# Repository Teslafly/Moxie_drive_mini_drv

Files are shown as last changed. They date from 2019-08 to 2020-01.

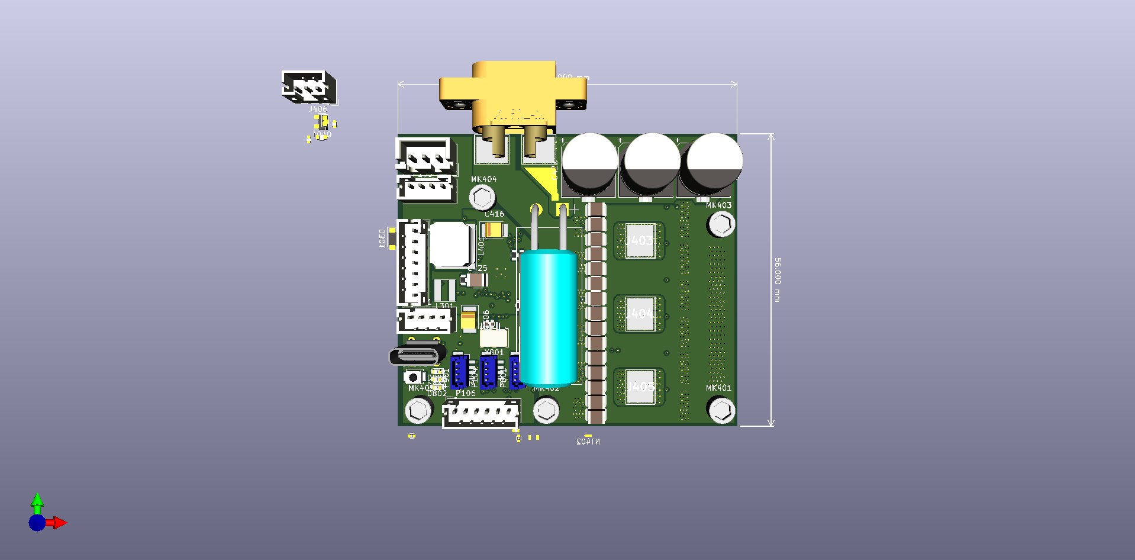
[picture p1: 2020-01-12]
MoxiE_drive mini front notrace 1-11-20.png

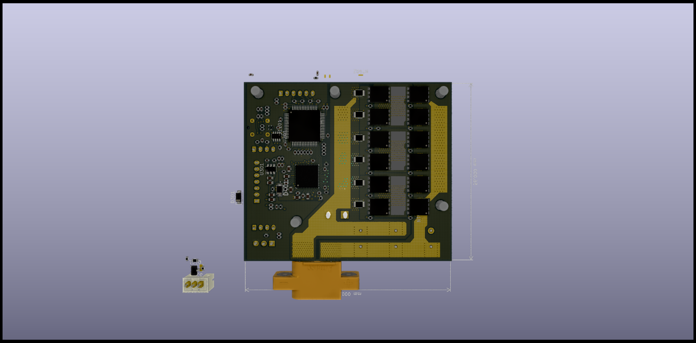
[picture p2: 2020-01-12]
MoxiE_drive mini back 1-11-20.png

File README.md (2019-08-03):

# Moxie_drive_mini_drv
A motor drive based off https://github.com/vedderb/bldc-hardware using the drv8353 and toshiba fets

MoxiE-Drive - high power 12-75v motor controller
=============

design

Forged from the remminants of the oppressed vesc 6.
Raised on a diet of endless sphere and equals zero posts.
destined for a fight to the death in hilariously brutal Power Wheels Racing Series.
I give to you, the MoxiE-Drive.

This the Hardware for my derivitive of the Vesc-project.

## Schematic top level


## Layout -made with KiCad!-


## 3D views



Have a look at this post for a tutorial on how to get started:
http://vedder.se/2015/01/vesc-open-source-esc/

Made with KiCad 5

wonderfulfailure.wordpress.com

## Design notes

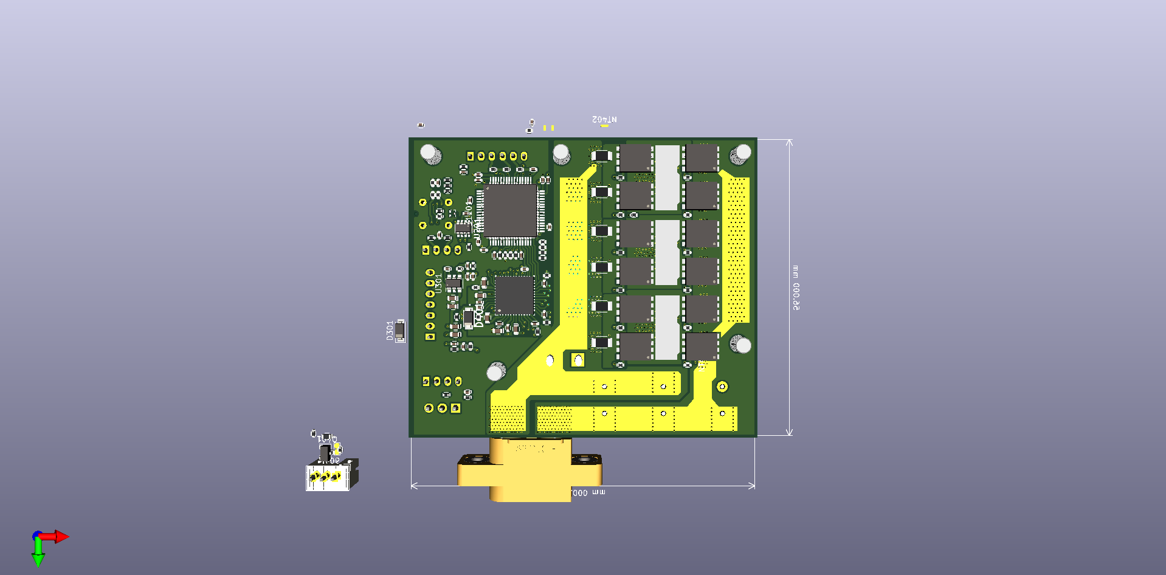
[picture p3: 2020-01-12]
MoxiE_drive mini back notrace 1-11-20.png

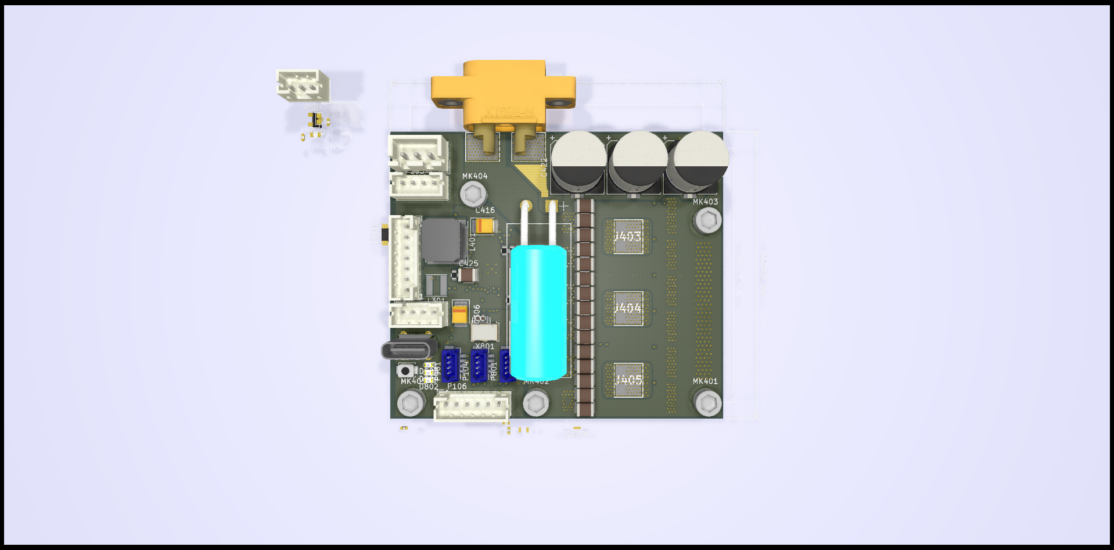
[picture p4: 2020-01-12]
MoxiE_drive mini front 1-11-20.png

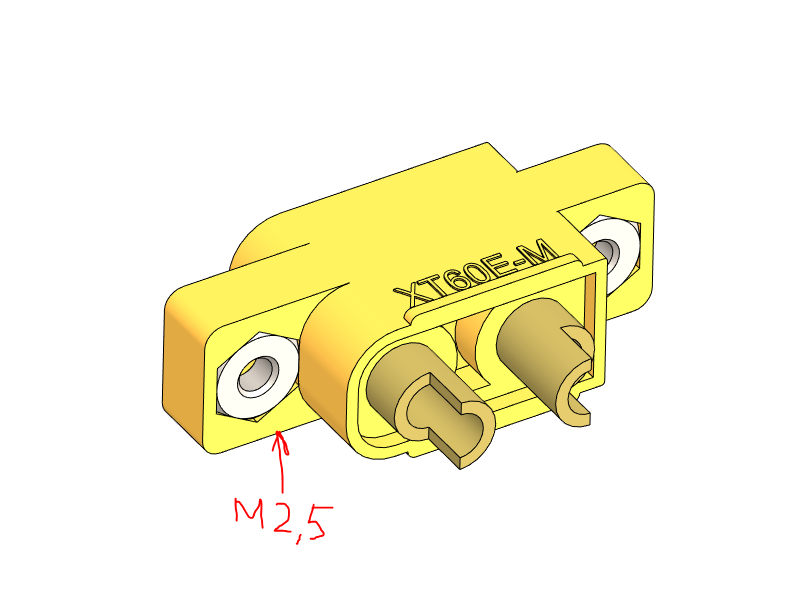
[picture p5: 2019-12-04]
3dmodels/xt-60-family-1.snapshot.6/v25.PNG

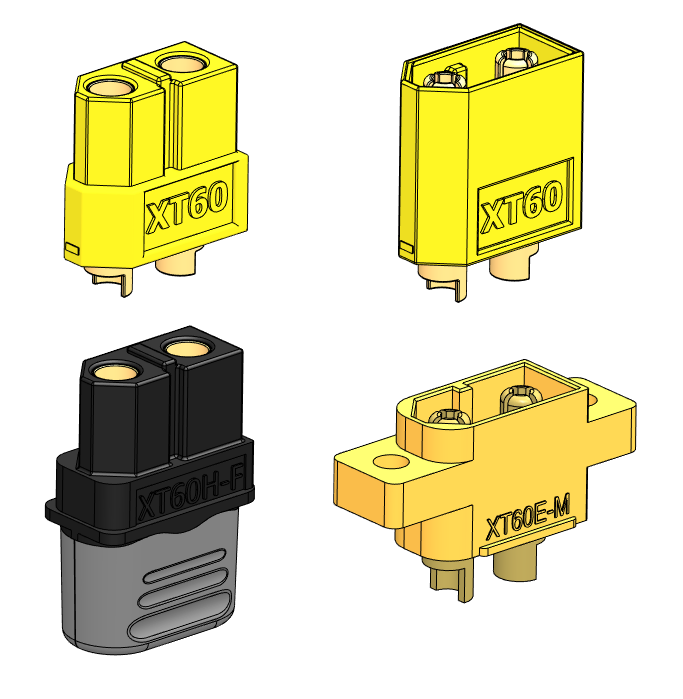
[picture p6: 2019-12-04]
3dmodels/xt-60-family-1.snapshot.6/xt60 fam.PNG

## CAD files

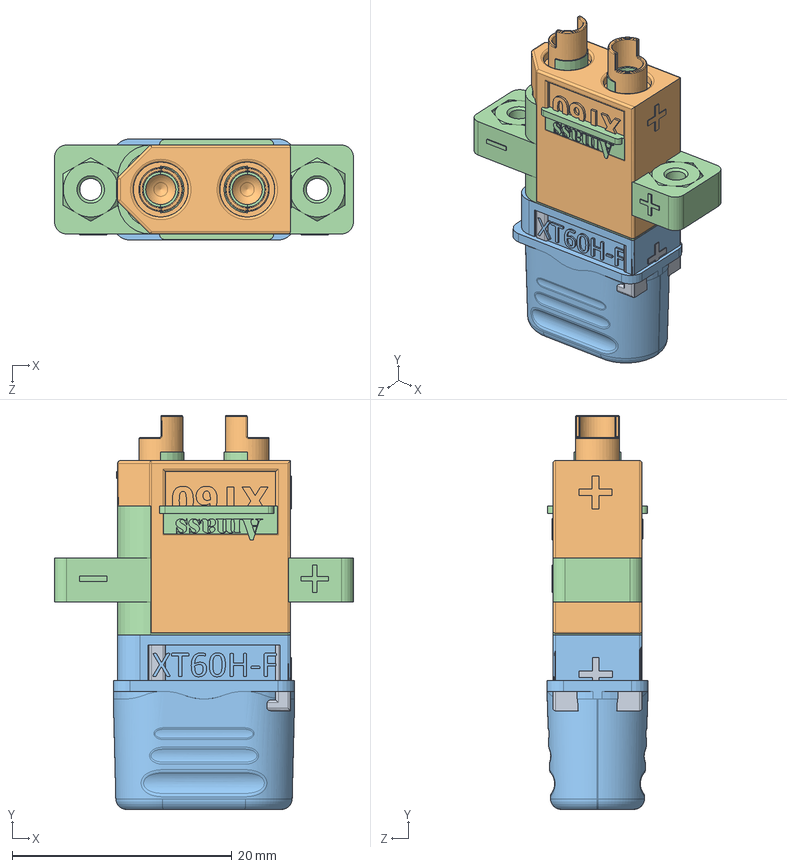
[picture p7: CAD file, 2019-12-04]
3dmodels/xt-60-family-1.snapshot.6/XT60 connect ASM.SLDASM
27.2 x 35.8 x 9.20 mm
XT60 Female Connector
XT60 Male Connector
XT60H-F
XT60E-M

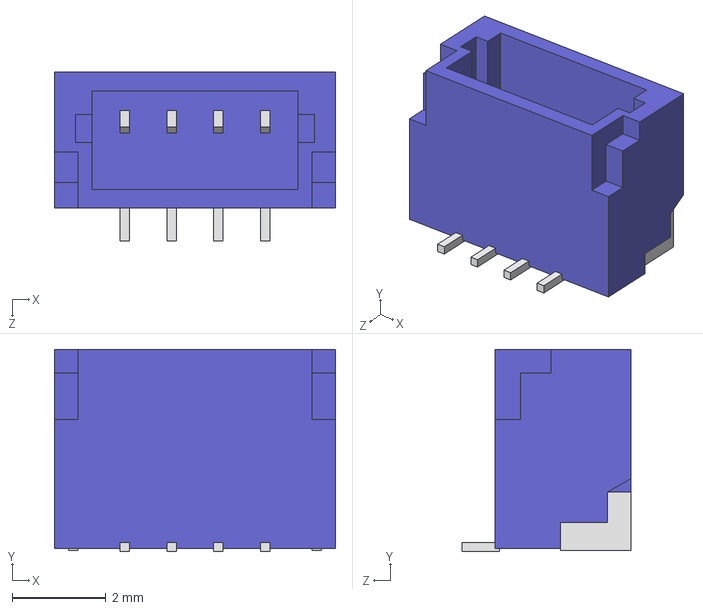
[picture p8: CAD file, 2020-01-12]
3dmodels/BM04B-SRSS-TB.STEP
6.00 x 4.32 x 3.60 mm

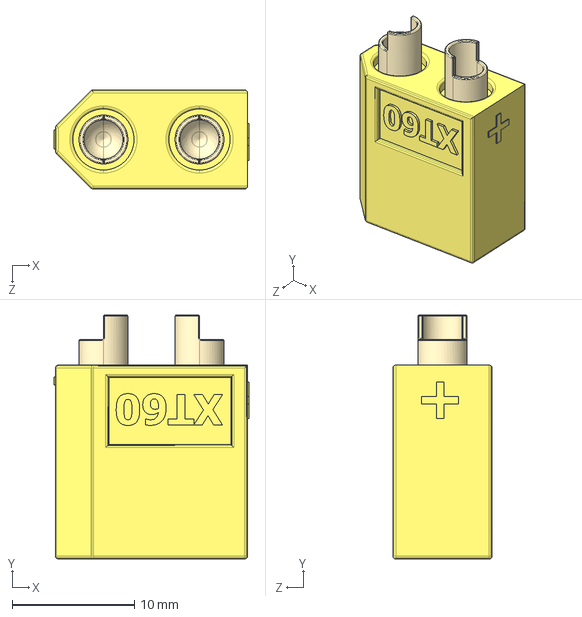
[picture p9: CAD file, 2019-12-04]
3dmodels/xt-60-family-1.snapshot.6/XT60 Male Connector.STEP
15.9 x 20.0 x 8.13 mm

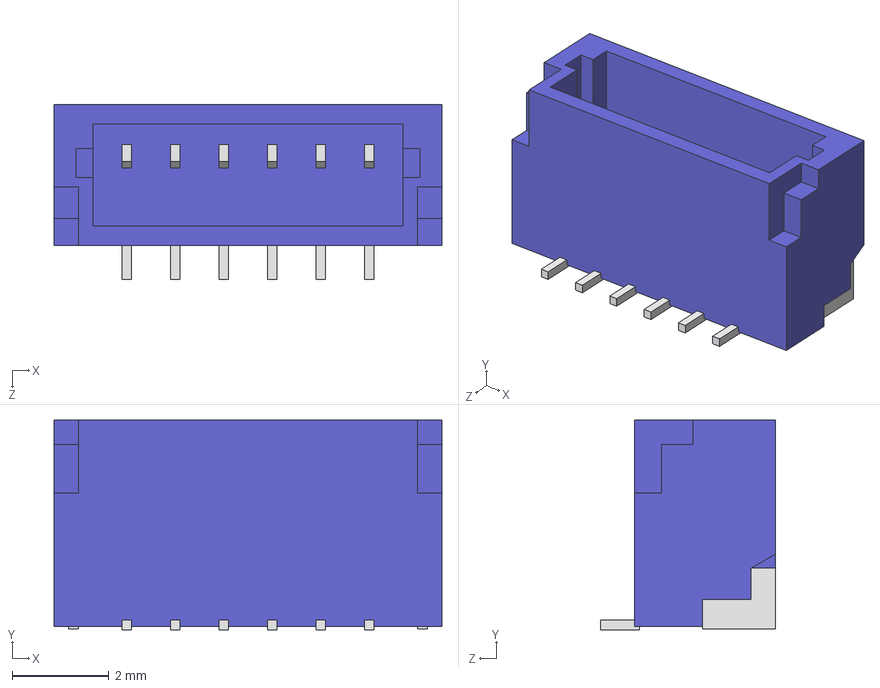
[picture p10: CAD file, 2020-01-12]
3dmodels/BM06B-SRSS-TB.STEP
8.00 x 4.32 x 3.60 mm

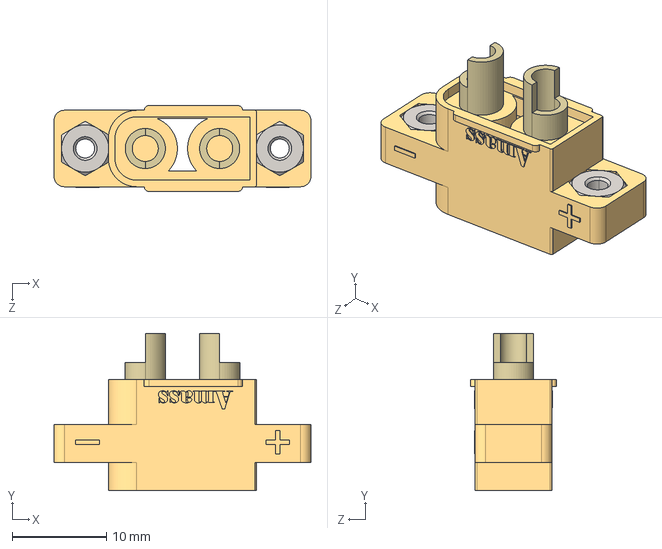
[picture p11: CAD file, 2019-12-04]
3dmodels/xt-60-family-1.snapshot.6/XT60E-M.STEP
27.2 x 16.7 x 9.10 mm

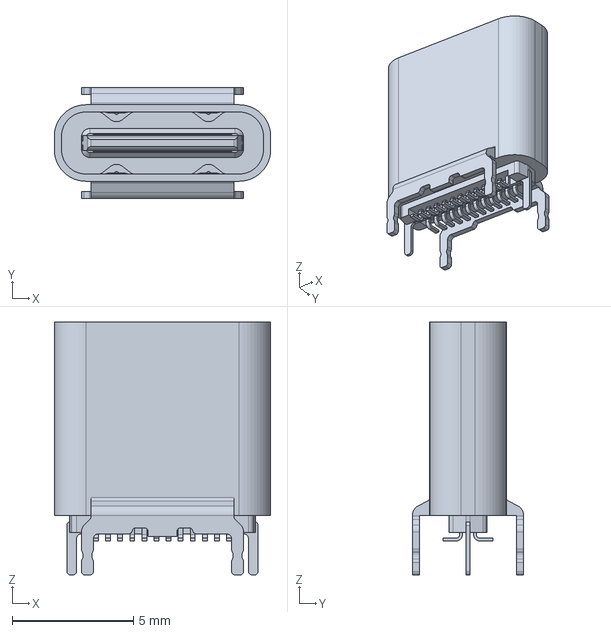
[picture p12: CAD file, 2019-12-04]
3dmodels/usb c 2047110001.stp
8.94 x 4.60 x 10.4 mm

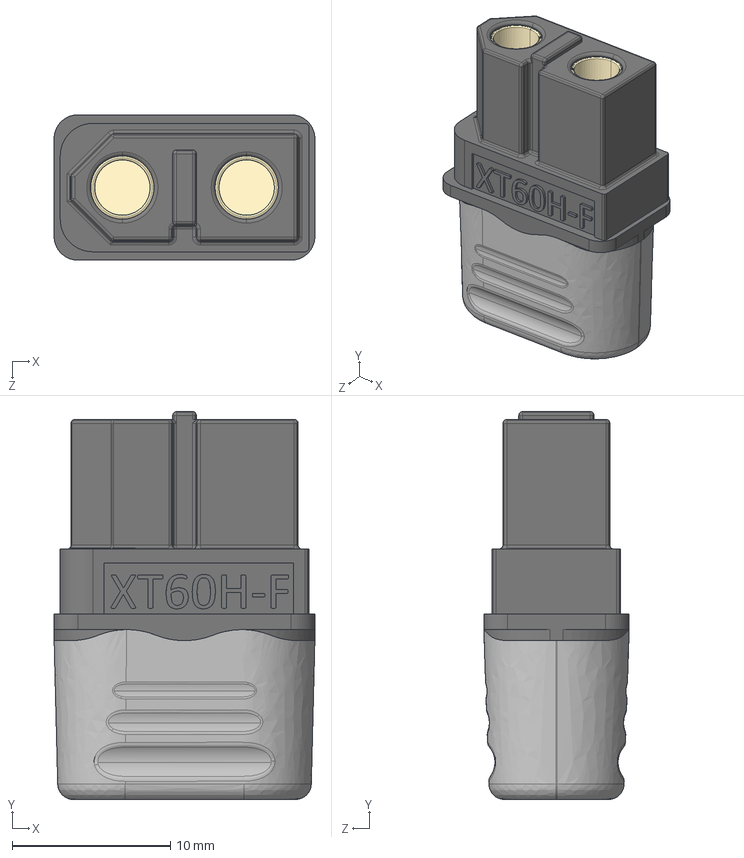
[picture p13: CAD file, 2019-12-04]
3dmodels/xt-60-family-1.snapshot.6/XT60H-F.STEP
16.5 x 24.5 x 9.20 mm

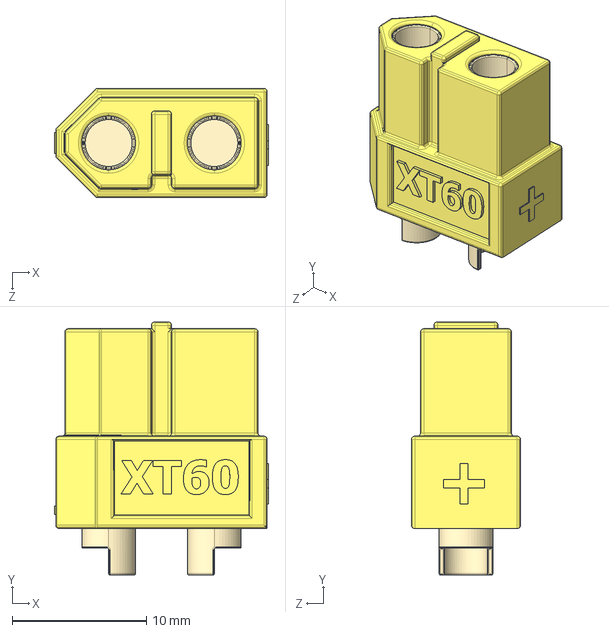
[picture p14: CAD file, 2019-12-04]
3dmodels/xt-60-family-1.snapshot.6/XT60 Female Connector.STEP
15.9 x 18.8 x 8.13 mm

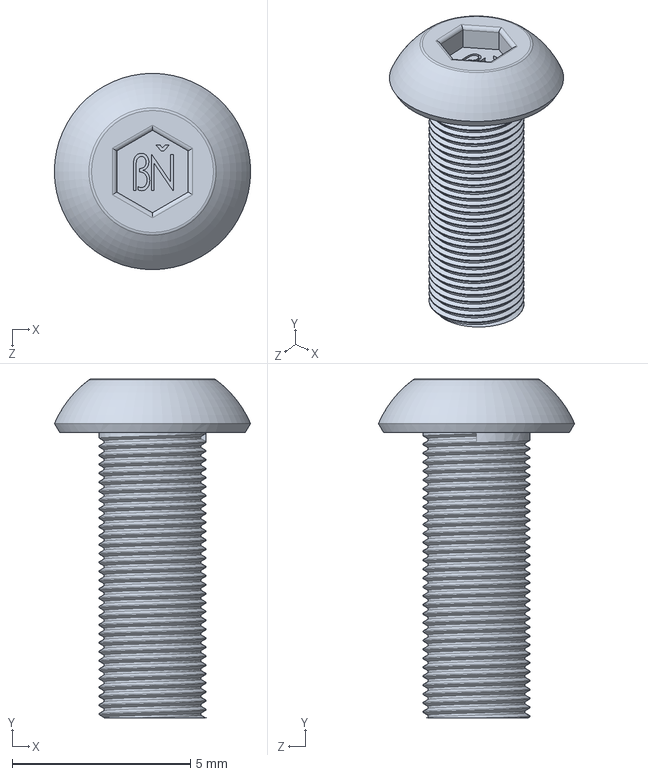
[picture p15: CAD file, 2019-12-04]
3dmodels/MachineScrews/Screw_Machine_M3x8.SLDPRT
5.50 x 9.50 x 5.50 mm

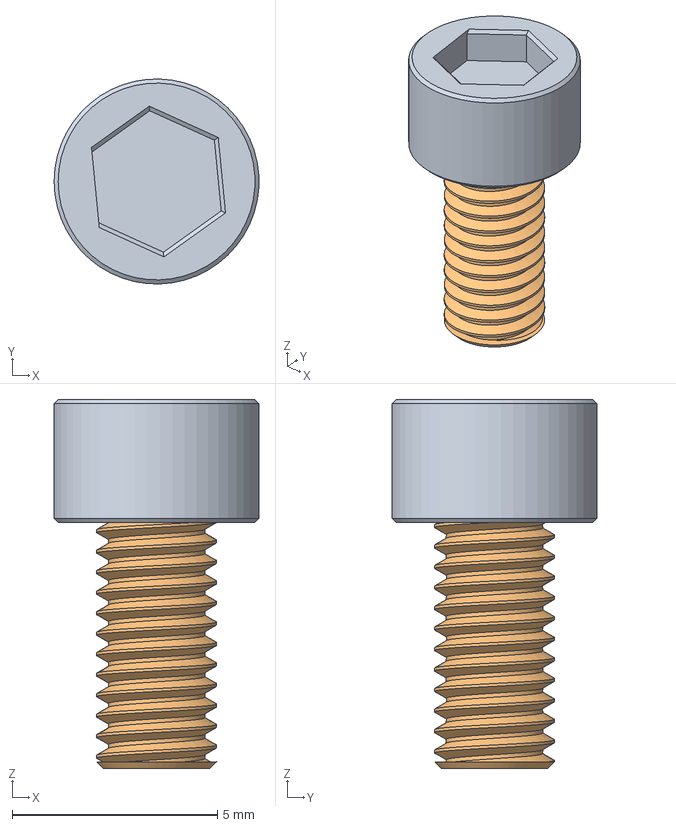
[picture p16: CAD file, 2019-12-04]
3dmodels/screw-m3-6mm-1.snapshot.1/screw M3 6mm .step
5.00 x 5.00 x 9.00 mm

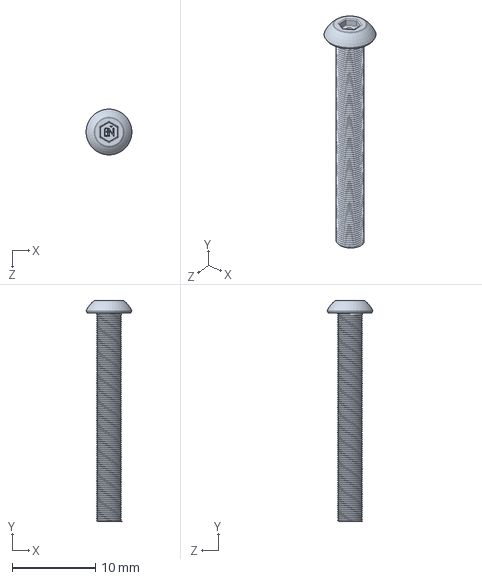
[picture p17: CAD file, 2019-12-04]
3dmodels/MachineScrews/Screw_Machine_M3x25.SLDPRT
5.50 x 26.5 x 5.50 mm

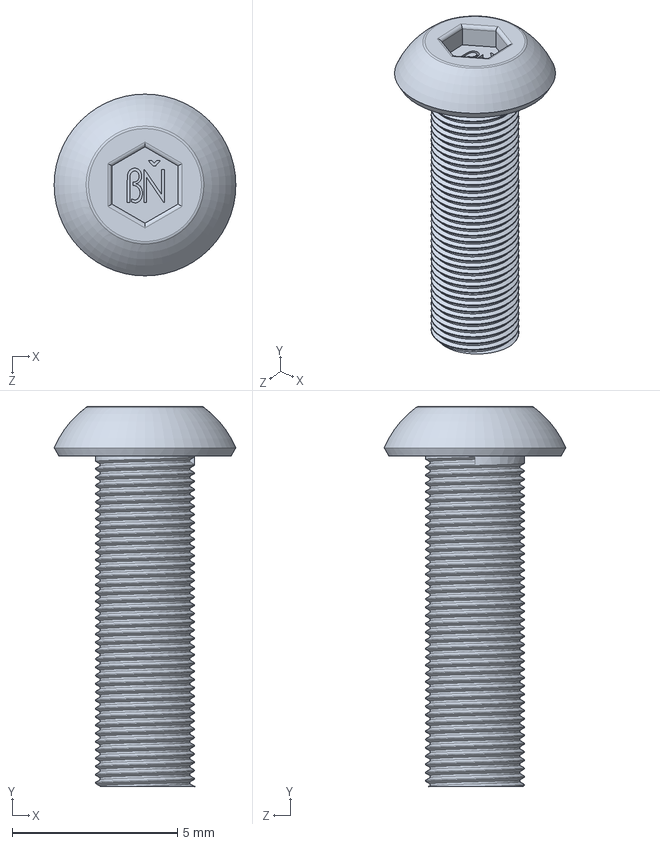
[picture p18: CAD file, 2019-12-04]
3dmodels/MachineScrews/Screw_Machine_M3x10.SLDPRT
5.50 x 11.5 x 5.50 mm

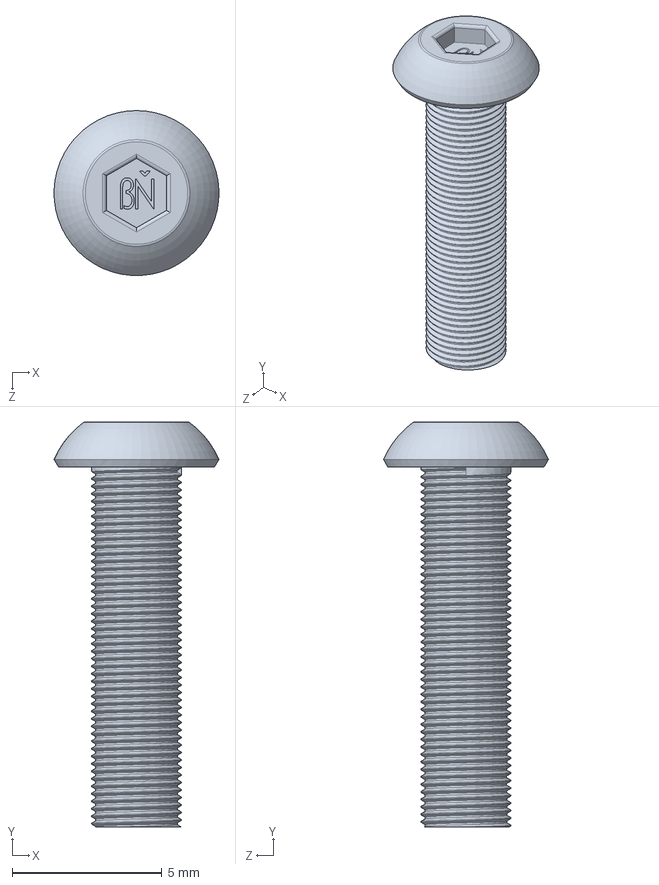
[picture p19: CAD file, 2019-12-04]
3dmodels/MachineScrews/Screw_Machine_M3x12.SLDPRT
5.50 x 13.5 x 5.50 mm

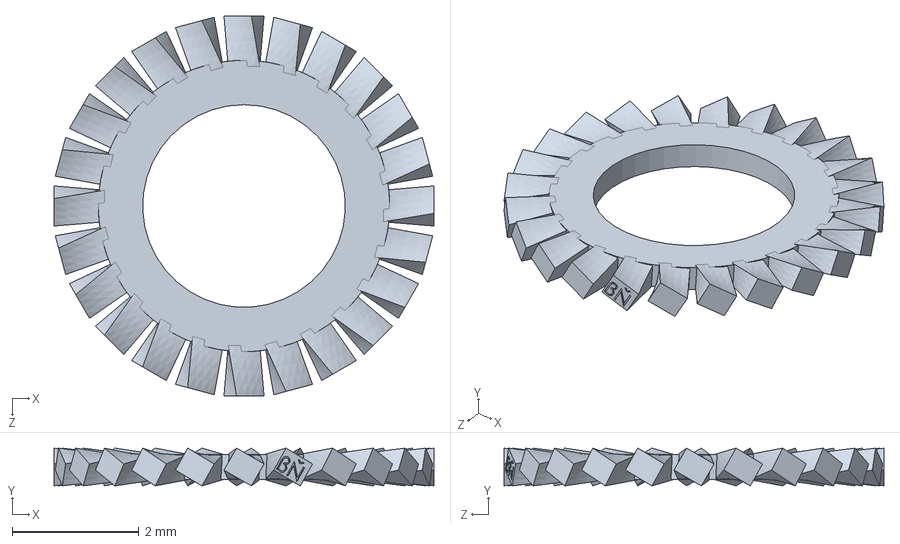
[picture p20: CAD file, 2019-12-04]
3dmodels/MachineScrews/Lock Washer_Bolt _M3.SLDPRT
6.00 x 0.596 x 6.00 mm

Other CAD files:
3dmodels/MachineScrews/Screw_Machine_M3x14.SLDPRT
3dmodels/MachineScrews/Nut_Machine_M3x2.SLDPRT
3dmodels/MachineScrews/Screw_Machine_M3x18.SLDPRT
3dmodels/MachineScrews/Screw_Machine_M3x16.SLDPRT
3dmodels/MachineScrews/Screw_Machine_M3x.SLDPRT
3dmodels/MachineScrews/Screw_Machine_M3x20.SLDPRT
3dmodels/MachineScrews/Screw_Machine_M3x6.SLDPRT
3dmodels/xt-60-family-1.snapshot.6/XT60 Female Connector.SLDPRT
3dmodels/xt-60-family-1.snapshot.6/XT60 Male Connector.SLDPRT
3dmodels/xt-60-family-1.snapshot.6/XT60E-M.SLDPRT
3dmodels/xt-60-family-1.snapshot.6/XT60H-F.SLDPRT

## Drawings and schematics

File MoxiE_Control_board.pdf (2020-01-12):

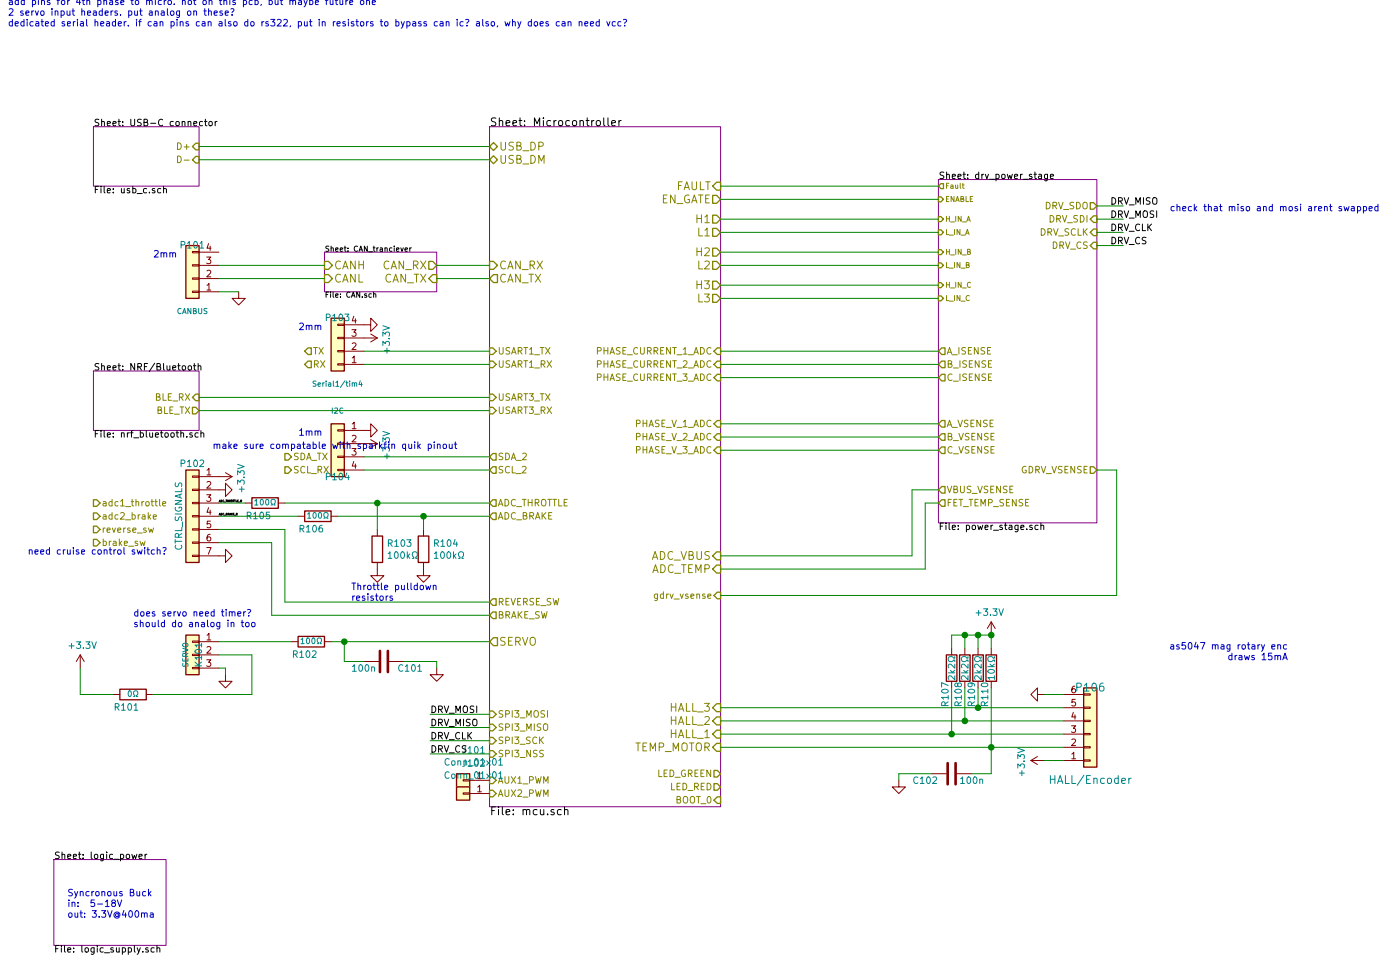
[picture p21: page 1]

add pins for 4th phase to micro. not on this pcb, but maybe future one
2 servo input headers. put analog on these?
dedicated serial header. if can pins can also do rs322, put in resistors to bypass can ic? also, why does can need vcc?

check that miso and mosi arent swapped

Sheet: NRF/Bluetooth File: nrf_bluetooth.sch BLE_TX

make sure compatable with sparkfin quik pinout

Throttle pulldown resistors need cruise control switch? Syncronous Buck

does servo need timer?
should do analog in too

as5047 mag rotary enc draws 15mA

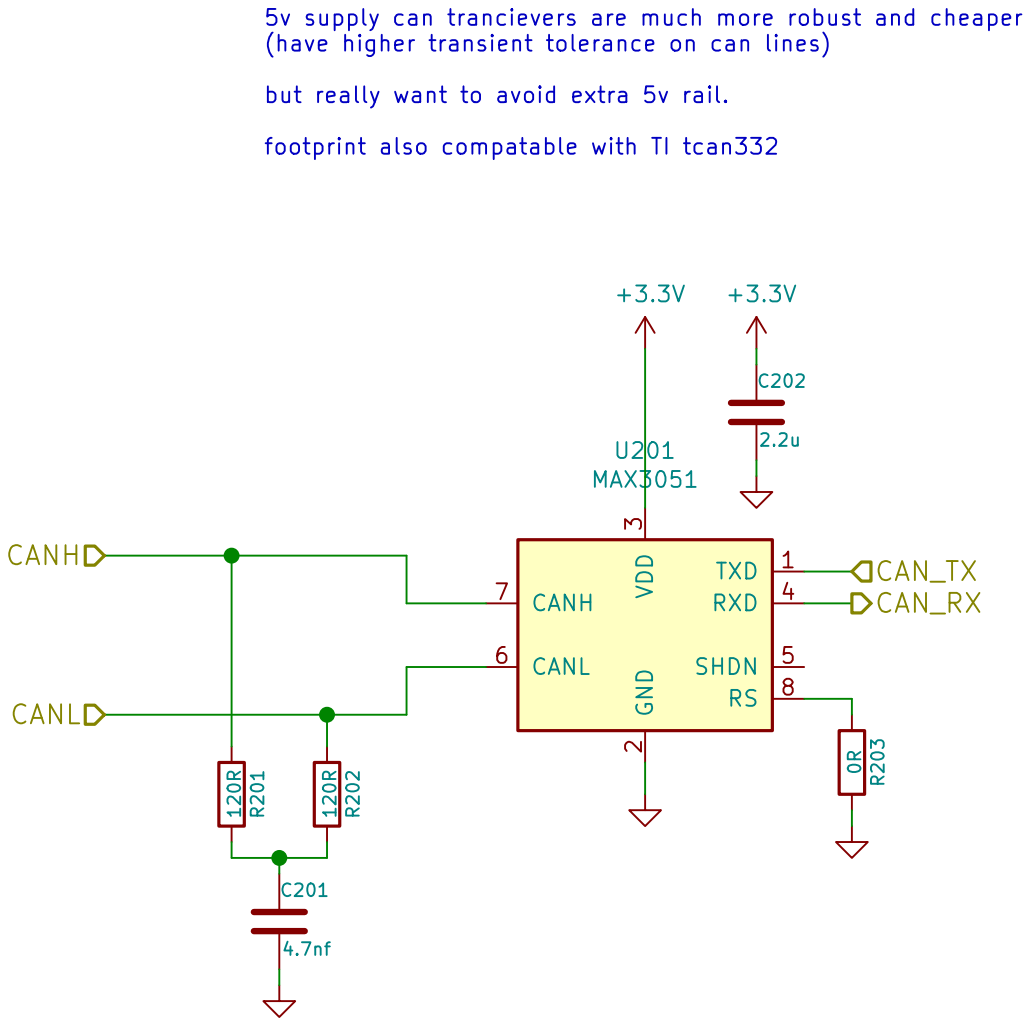
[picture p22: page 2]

5v supply can trancievers are much more robust and cheaper
(have higher transient tolerance on can lines)

but really want to avoid extra 5v rail.

footprint also compatable with TI tcan332

3 RXD 4 SHDN 5 CANL 6 CANH 7 RS 8 U201 MAX3051 R203 0R

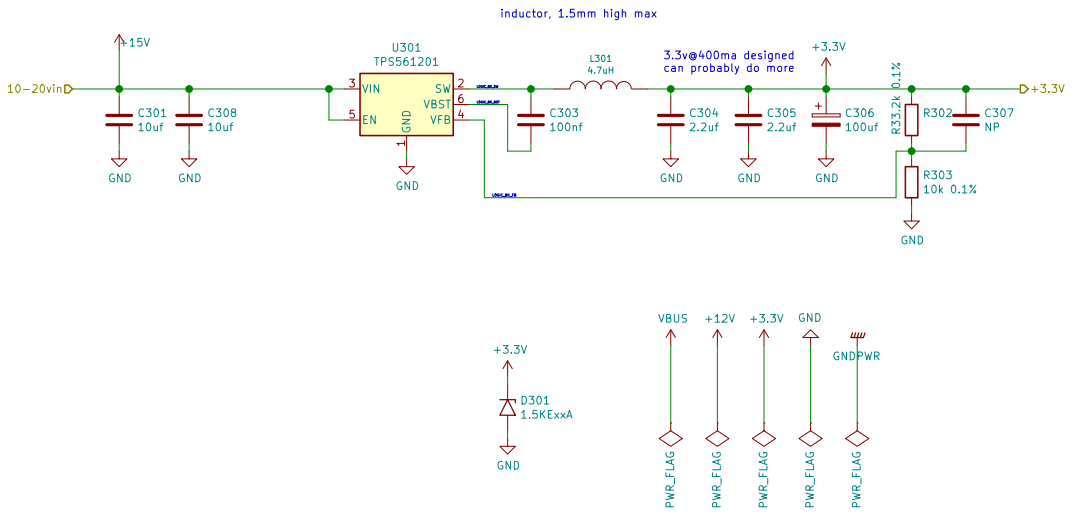
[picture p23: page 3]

1 SW 2 VIN 3 VFB 4 EN 5 VBST 6 U301 TPS561201 D301

3.3v@400ma designed
can probably do more

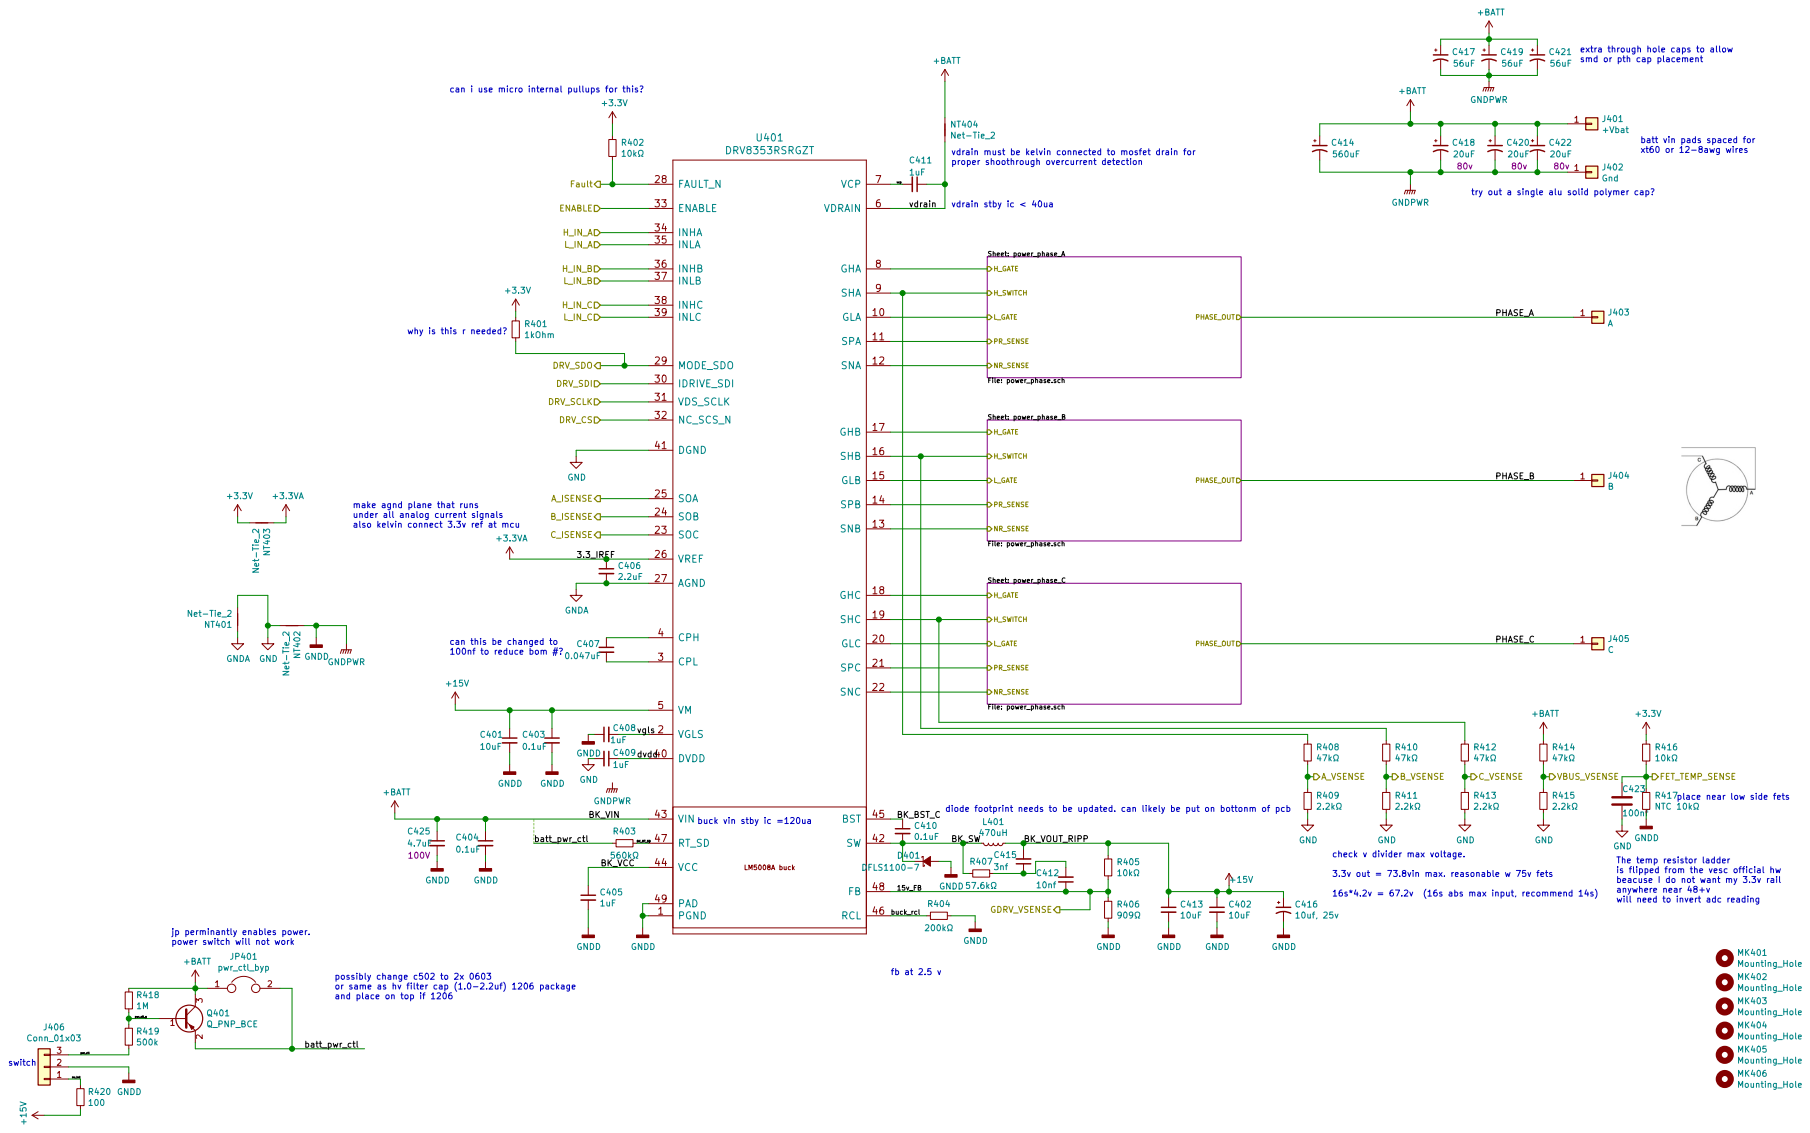
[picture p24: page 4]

extra through hole caps to allow
smd or pth cap placement

can i use micro internal pullups for this?

batt vin pads spaced for
xt60 or 12-8awg wires

vdrain must be kelvin connected to mosfet drain for proper shoothrough overcurrent detection

try out a single alu solid polymer cap?

under all analog current signals also kelvin connect 3.3v ref at mcu why is this r needed?

make agnd plane that runs

diode footprint needs to be updated. can likely be put on bottonm of pcb

buck vin stby ic =120ua

check v divider max voltage. 3.3v out = 73.8vin max. reasonable w 75v fets 16s*4.2v = 67.2v (16s abs max input, recommend 14s)

is flipped from the vesc official hw
beacuse I do not want my 3.3v rail
anywhere near 48+v
will need to invert adc reading

jp perminantly enables power.
power switch will not work

possibly change c502 to 2x 0603
or same as hv filter cap (1.0-2.2uf) 1206 package
and place on top if 1206

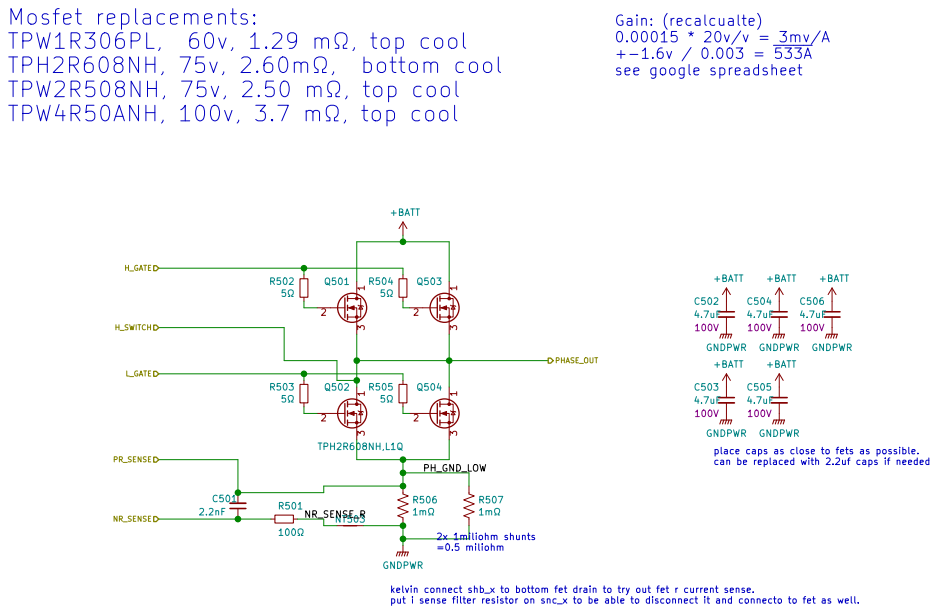
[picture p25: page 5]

GNDPWR
place caps as close to fets as possible.
can be replaced with 2.2uf caps if needed

kelvin connect shb_x to bottom fet drain to try out fet r current sense.
put i sense filter resistor on snc_x to be able to disconnect it and connecto to fet as well.

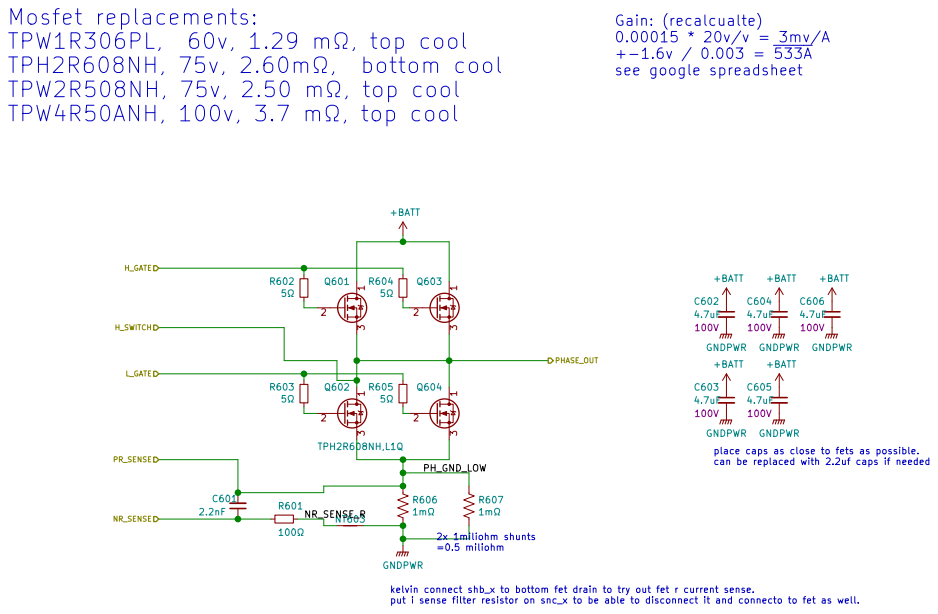
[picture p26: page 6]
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

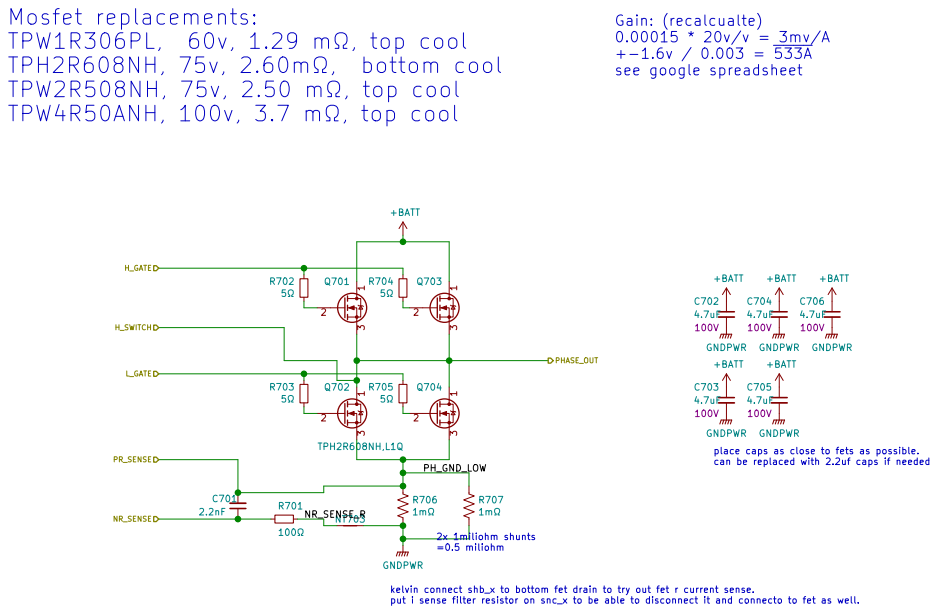
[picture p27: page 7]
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

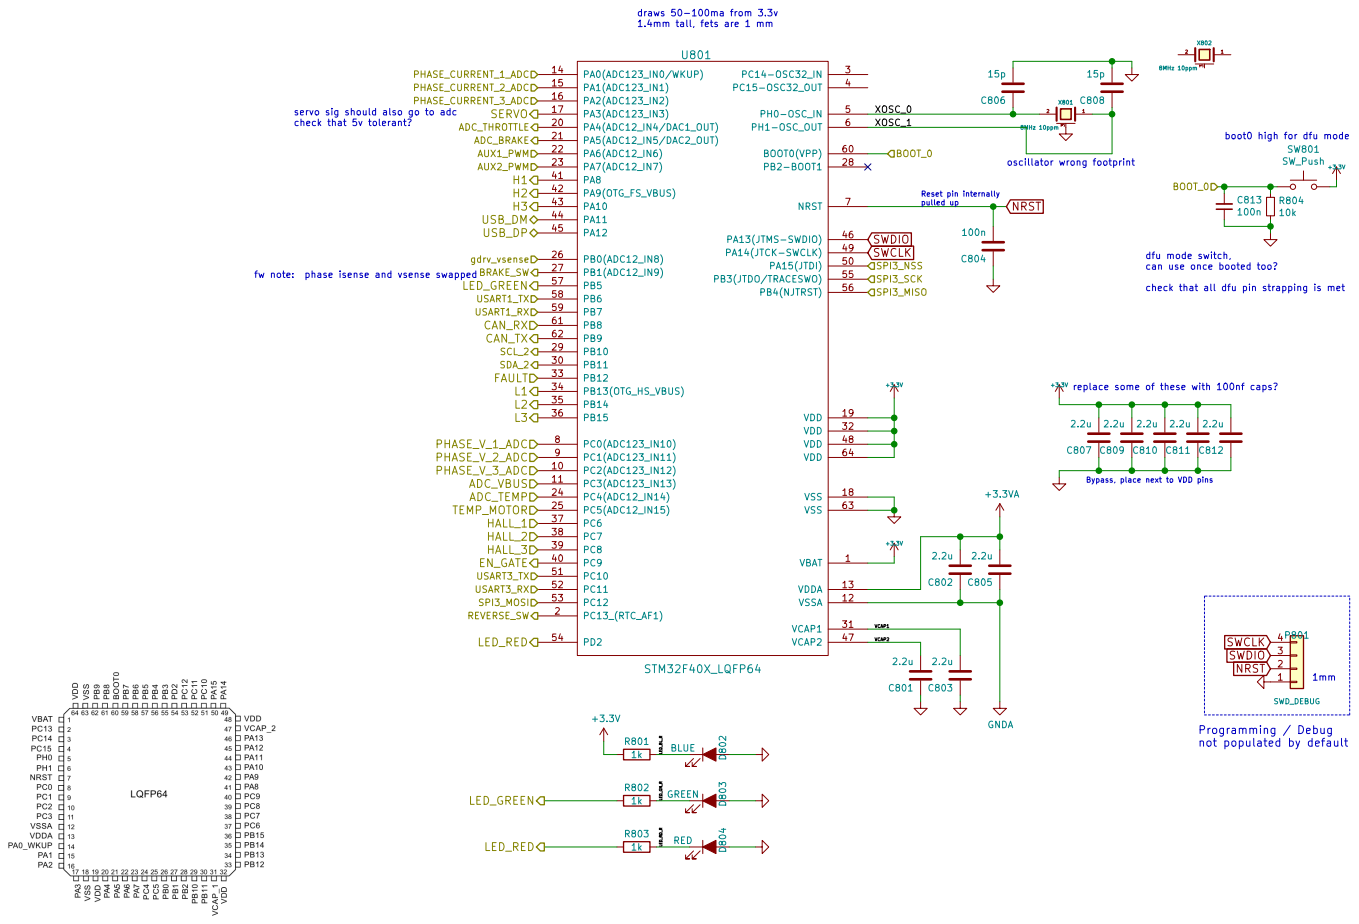
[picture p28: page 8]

draws 50-100ma from 3.3v 1.4mm tall, fets are 1 mm

servo sig should also go to adc
check that 5v tolerant?

fw note: phase isense and vsense swapped

check that all dfu pin strapping is met

replace some of these with 100nf caps?

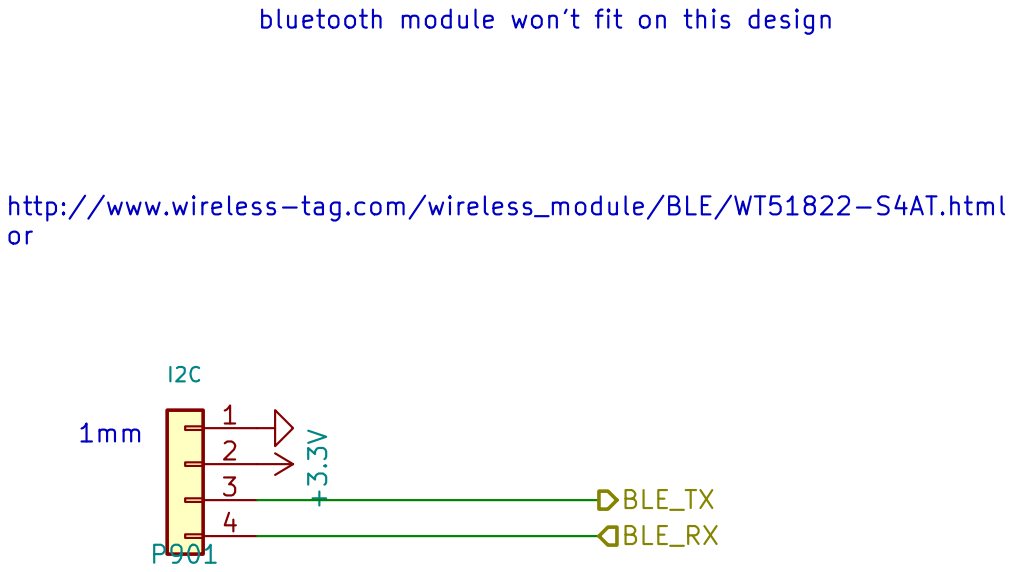
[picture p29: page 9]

bluetooth module won't fit on this design

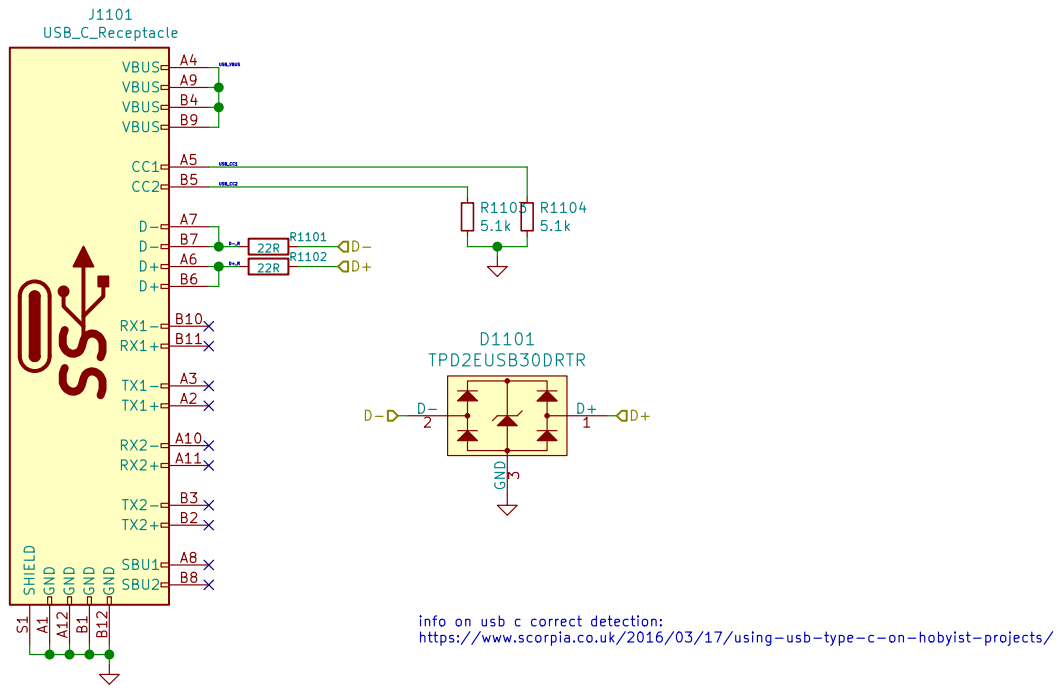
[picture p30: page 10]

info on usb c correct detection: https://www.scorpia.co.uk/2016/03/17/using-usb-type-c-on-hobyist-projects/

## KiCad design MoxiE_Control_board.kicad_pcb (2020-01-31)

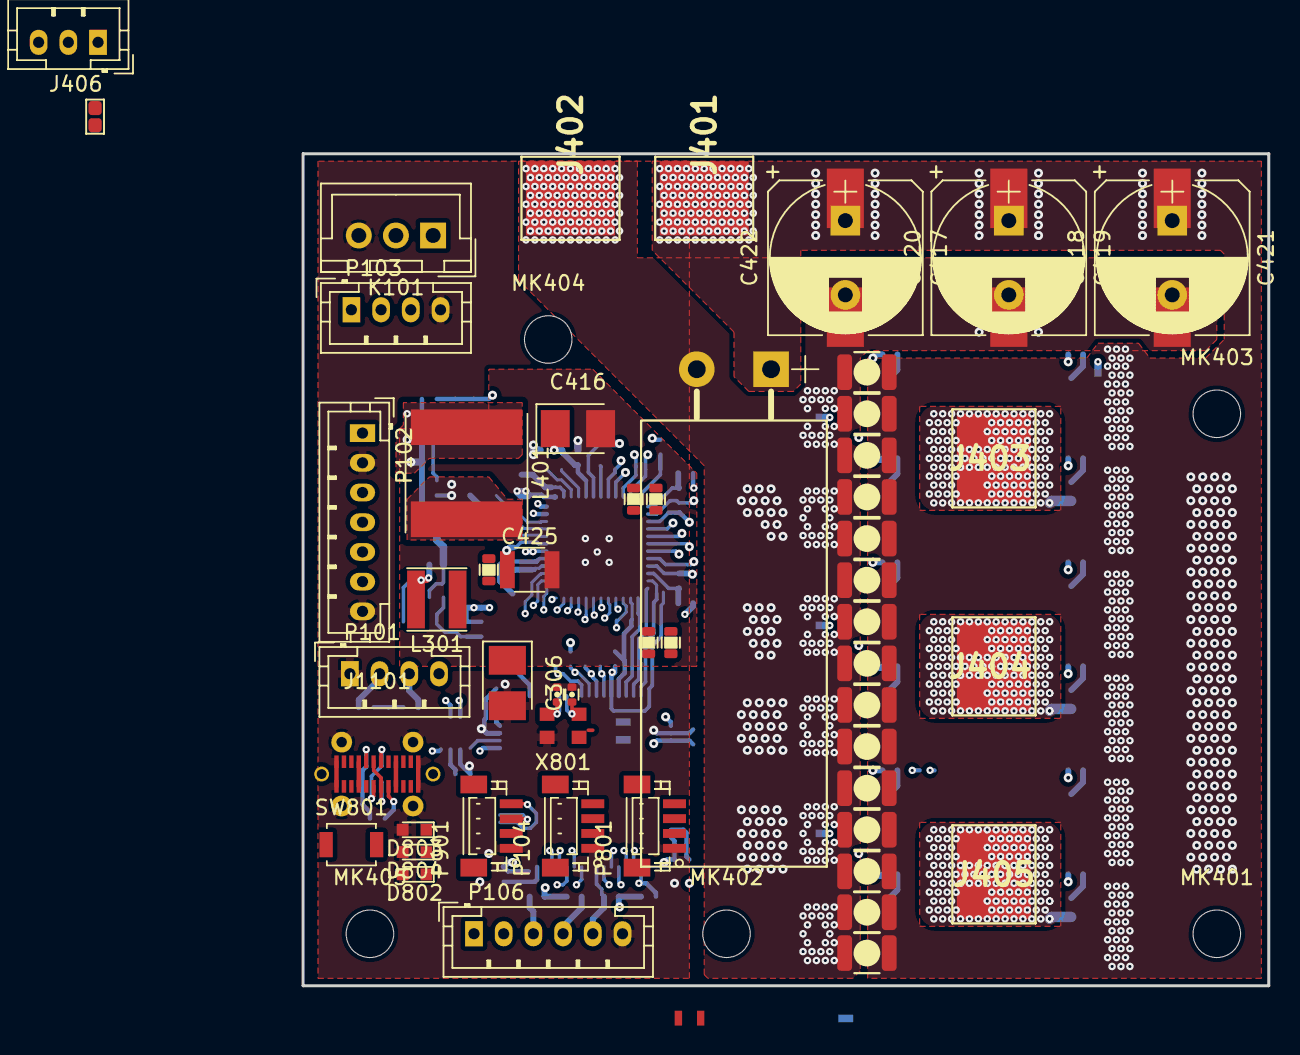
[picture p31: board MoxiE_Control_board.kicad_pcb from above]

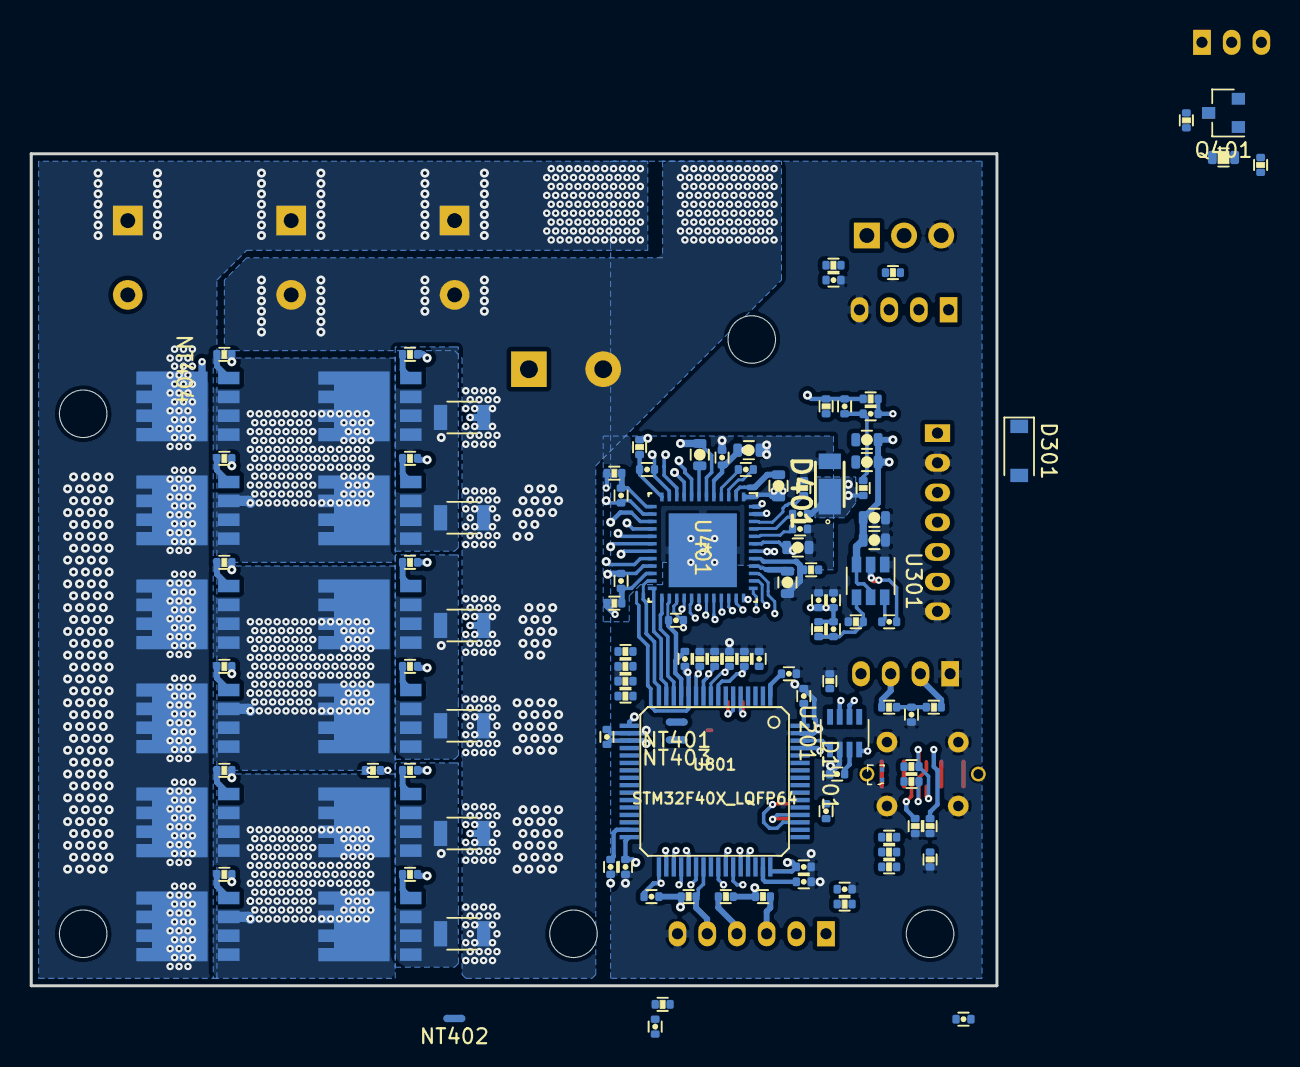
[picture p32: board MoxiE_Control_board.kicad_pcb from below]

Board: 4 copper layers, 65.0 x 56.0 mm, 187 parts (125 on the bottom side), 125 nets.

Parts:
C101, C102, C804: 100n; C_0402
C201: 4.7nf; C_0402
C202, C801, C802, C803, C805, C807, C809, C810, C811, C812: 2.2u; C_0402
C301, C308: 10uf; C_0603
C303, C423: 100nf; C_0402
C304, C305: 2.2uf; C_0402
C306: 100uf; CP_Tantalum_Case-B_EIA-3528-21_Reflow
C307: NP; C_0402
C401, C402, C413: 10uF; C_0603
C403, C410: 0.1uF; C_0402
C404: 0.1uF; C_0603
C405: 1uF; C_0402
C406: 2.2uF; C_0402
C407: 0.047uF; C_0402
C408, C409, C411: 1uF; C_0603
C412: 10nf; C_0402
C414: 560uF; CP_Radial_D12.5mm_P5.00mm_horiz
C415: 3nf; C_0402
C416: 10uf, 25v; CP_Tantalum_Case-B_EIA-3528-21_Reflow
C417, C419, C421: 56uF; CP_Radial_D10.0mm_P5.00mm
C418, C420, C422: 20uF; CP_Elec_10x10.5
C425, C502, C503, C504, C505, C506, C602, C603, C604, C605, C606, C702, C703, C704, C705, C706: 4.7uF; C_1210
C501, C601, C701: 2.2nF; C_0402
C806, C808: 15p; C_0402
D301: 1.5KExxA; D_SOD-123
D401: DFLS1100-7; POWERDI123_1
D802: BLUE; LED_0603
D803: GREEN; LED_0603
D804: RED; LED_0603
D1101: TPD2EUSB30DRTR; SOT-3
J101, J102: Conn_01x01; SMD_Pad_Array-1_Pitch1mm
J401: +Vbat; 1PAD_6x5mm
J402: Gnd; 1PAD_6x5mm
J403: A; 1PAD_6x5mm
J404: B; 1PAD_6x5mm
J405: C; 1PAD_6x5mm
J406: Conn_01x03; JST_PH_B3B-PH-K_03x2.00mm_Straight
J1101: USB_C_Receptacle; USB_C_receptacle_vertical
JP401: pwr_ctl_byp; J_0603
K101: SERVO; JST_XH_B03B-XH-A_03x2.50mm_Straight
L301: 4.7uH; L_Taiyo-Yuden_NR-40xx
L401: 470uH; L_wurth-8065
MK401, MK402, MK403, MK404, MK405: Mounting_Hole; MountingHole_3.2mm_M3_DIN965
NT401, NT402, NT403, NT404, NT503, NT603, NT703: Net-Tie_2; NetTie-2_SMD_Pad0.5mm
P101: CANBUS; JST_PH_B4B-PH-K_04x2.00mm_Straight
P102: CTRL_SIGNALS; JST_PH_B7B-PH-K_07x2.00mm_Straight
P103: Serial1/tim4; JST_PH_B4B-PH-K_04x2.00mm_Straight
P104, P901: I2C; JST_SH_BM04B-SRSS-TB_04x1.00mm_Straight
P106: HALL/Encoder; JST_PH_B6B-PH-K_06x2.00mm_Straight
P801: SWD_DEBUG; JST_SH_BM04B-SRSS-TB_04x1.00mm_Straight
Q401: Q_PNP_BCE; SOT-23
Q501, Q502, Q503, Q504, Q601, Q602, Q603, Q604, Q701, Q702, Q703, Q704: TPH2R608NH,L1Q; SOP8_Advance
R101: 0Ω; R_0402
R102, R105, R106, R501, R601, R701: 100Ω; R_0402
R103, R104: 100kΩ; R_0402
R107, R108, R109: 2k2Ω; R_0402
R110, R405, R416: 10kΩ; R_0402
R201, R202: 120R; R_0402
R203: 0R; R_0402
R302: R33.2k 0.1%; R_0402
R303: 10k 0.1%; R_0402
R401: 1kOhm; C_0402
R402: 10kΩ; C_0402
R403: 560kΩ; R_0402
R404: 200kΩ; R_0402
R406: 909Ω; R_0402
R407: 57.6kΩ; R_0402
R408, R410, R412, R414: 47kΩ; R_0603
R409, R411, R413, R415: 2.2kΩ; R_0402
R417: NTC 10kΩ; R_0402
R418: 1M; R_0402
R419: 500k; R_0603
R420: 100; R_0402
R421: 0Ω; R_0603
R502, R503, R504, R505, R602, R603, R604, R605, R702, R703, R704, R705: 5Ω; R_0402
R506, R507, R606, R607, R706, R707: 1mΩ; R_1206
R801, R802, R803, R804: 1k; R_0402
R1101, R1102: 22R; R_0402
R1103, R1104: 5.1k; R_0402
SW801: SW_Push; SW_SPST_B3U-1000P
U201: MAX3051; SOT-23-8
U301: TPS561201; SOT-23-6
U401: DRV8353RSRGZT; DRV8353RHRGZR
U801: STM32F40X_LQFP64; lqfp64_pad_mod
X801: 8MHz 10ppm; Oscillator_SMD_EuroQuartz_XO32-4pin_3.2x2.5mm

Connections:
+3.3VA: C406.1, C802.2, C805.2, NT403.1, U401.26, U801.13
+3V3: C202.1, C304.1, C305.1, C306.1, C307.1, C807.2, C809.2, C810.2, C811.2, C812.2, D301.1, L301.1, NT403.2, P102.1, P103.3, P104.2, P106.1, P901.2, R101.2, R107.2, R108.2, R109.2, R110.2, R302.1, R401.1, R402.1, R416.1, R801.2, SW801.2, U201.3, U801.1, U801.19, U801.32, U801.48, U801.64
+15V: C301.1, C308.1, C401.1, C402.1, C403.1, C413.1, C415.2, C416.1, L401.1, R405.1, R420.2, U301.3, U301.5, U401.5
+BATT: C414.1, C417.1, C418.1, C419.1, C420.1, C421.1, C422.1, C502.1, C503.1, C504.1, C505.1, C506.1, C602.1, C603.1, C604.1, C605.1, C606.1, C702.1, C703.1, C704.1, C705.1, C706.1, J401.1, JP401.1, NT404.1, Q401.3, Q501.1, Q503.1, Q601.1, Q603.1, Q701.1, Q703.1, R414.1, R418.1, R421.1
/ADC_BRAKE_R: P102.4, R106.2
/ADC_THROTTLE_R: P102.3, R105.2
/CAN_tranciever/CANH: P101.3, R201.1, U201.7
/CAN_tranciever/CANL: P101.2, R202.1, U201.6
/CAN_tranciever/CAN_RX: U201.4, U801.61
/CAN_tranciever/CAN_TX: U201.1, U801.62
/DRV_CLK: U401.31, U801.55
/DRV_CS: U401.32, U801.50
/DRV_MISO: R401.2, U401.29, U801.56
/DRV_MOSI: U401.30, U801.53
/Microcontroller/ADC_BRAKE: R104.1, R106.1, U801.21
/Microcontroller/ADC_TEMP: C423.1, R416.2, R417.1, U801.24
/Microcontroller/ADC_THROTTLE: R103.1, R105.1, U801.20
/Microcontroller/ADC_VBUS: R414.2, R415.1, U801.11
/Microcontroller/AUX1_PWM: J101.1, U801.22
/Microcontroller/AUX2_PWM: J102.1, U801.23
/Microcontroller/BOOT_0: R804.1, SW801.1, U801.60
/Microcontroller/BRAKE_SW: P102.6, U801.27
/Microcontroller/FAULT: R402.2, U401.28, U801.33
/Microcontroller/H1: U401.34, U801.41
/Microcontroller/H2: U401.36, U801.42
/Microcontroller/H3: U401.38, U801.43
/Microcontroller/HALL_1: P106.3, R107.1, U801.37
/Microcontroller/HALL_2: P106.4, R108.1, U801.38
/Microcontroller/HALL_3: P106.5, R109.1, U801.39
/Microcontroller/L1: U401.35, U801.34
/Microcontroller/L2: U401.37, U801.35
/Microcontroller/L3: U401.39, U801.36
/Microcontroller/LED_BL_R: D802.1, R801.1
/Microcontroller/LED_GN_R: D803.1, R802.1
/Microcontroller/LED_GREEN: R802.2, U801.57
/Microcontroller/LED_RD_R: D804.1, R803.1
/Microcontroller/LED_RED: R803.2, U801.54
/Microcontroller/REVERSE_SW: P102.5, U801.2
/Microcontroller/SCL_2: P104.4, U801.29
/Microcontroller/SDA_2: P104.3, U801.30
/Microcontroller/SERVO: C101.2, R102.1, U801.17
/Microcontroller/TEMP_MOTOR: C102.2, P106.2, R110.1, U801.25
/Microcontroller/USART1_RX: P103.1, U801.59
/Microcontroller/USART1_TX: P103.2, U801.58
/Microcontroller/VCAP1: C803.2, U801.31
/Microcontroller/VCAP2: C801.2, U801.47
/Microcontroller/XOSC_0: C806.1, U801.5, X801.2
/Microcontroller/XOSC_1: C808.1, U801.6, X801.1
/NRF/Bluetooth/BLE_RX: P901.4, U801.51
/NRF/Bluetooth/BLE_TX: P901.3, U801.52
/USB-C connector/D+: D1101.1, R1102.1, U801.45
/USB-C connector/D-: D1101.2, R1101.1, U801.44
/drv_power_stage/A_ISENSE: U401.25, U801.14
/drv_power_stage/A_VSENSE: R408.2, R409.1, U801.8
/drv_power_stage/BK_BST_C: C410.1, U401.45
/drv_power_stage/BK_RT_SD: R403.2, U401.47
/drv_power_stage/BK_SW: C410.2, D401.1, L401.2, R407.2, U401.42
/drv_power_stage/BK_VCC: C405.1, U401.44
/drv_power_stage/BK_VIN: C404.1, C425.1, R403.1, R421.2, U401.43
/drv_power_stage/B_ISENSE: U401.24, U801.15
/drv_power_stage/B_VSENSE: R410.2, R411.1, U801.9
/drv_power_stage/C_ISENSE: U401.23, U801.16
/drv_power_stage/C_VSENSE: R412.2, R413.1, U801.10
/drv_power_stage/ENABLE: U401.33, U801.40
/drv_power_stage/GDRV_VSENSE: C412.1, R405.2, R406.1, U401.48, U801.26
/drv_power_stage/PHASE_A: J403.1, Q701.3, Q702.1, Q703.3, Q704.1, R408.1, U401.9
/drv_power_stage/PHASE_B: J404.1, Q601.3, Q602.1, Q603.3, Q604.1, R410.1, U401.16
/drv_power_stage/PHASE_C: J405.1, Q501.3, Q502.1, Q503.3, Q504.1, R412.1, U401.19
/drv_power_stage/batt_pwr_ctl: JP401.2, Q401.2
/drv_power_stage/buck_rcl: R404.2, U401.46
/drv_power_stage/dvdd: C409.1, U401.40
/drv_power_stage/power_phase_A/H_GATE: R702.2, R704.2, U401.8
/drv_power_stage/power_phase_A/L_GATE: R703.2, R705.2, U401.10
/drv_power_stage/power_phase_A/NR_SENSE: C701.1, R701.1, U401.12
/drv_power_stage/power_phase_A/NR_SENSE_R: NT703.1, R701.2
/drv_power_stage/power_phase_A/PR_SENSE: C701.2, Q702.3, Q704.3, R706.1, R707.1, U401.11
/drv_power_stage/power_phase_B/H_GATE: R602.2, R604.2, U401.17
/drv_power_stage/power_phase_B/L_GATE: R603.2, R605.2, U401.15
/drv_power_stage/power_phase_B/NR_SENSE: C601.1, R601.1, U401.13
/drv_power_stage/power_phase_B/NR_SENSE_R: NT603.1, R601.2
/drv_power_stage/power_phase_B/PR_SENSE: C601.2, Q602.3, Q604.3, R606.1, R607.1, U401.14
/drv_power_stage/power_phase_C/H_GATE: R502.2, R504.2, U401.18
/drv_power_stage/power_phase_C/L_GATE: R503.2, R505.2, U401.20
/drv_power_stage/power_phase_C/NR_SENSE: C501.1, R501.1, U401.22
/drv_power_stage/power_phase_C/NR_SENSE_R: NT503.1, R501.2
/drv_power_stage/power_phase_C/PR_SENSE: C501.2, Q502.3, Q504.3, R506.1, R507.1, U401.21
/drv_power_stage/pwr_ctl: J406.3, R419.2
/drv_power_stage/pwr_ctl_g: Q401.1, R418.2, R419.1
/drv_power_stage/sw_led: J406.1, R420.1
/drv_power_stage/vcp: C411.2, U401.7
/drv_power_stage/vdrain: C411.1, NT404.2, U401.6
/drv_power_stage/vgls: C408.2, U401.2
GND: C101.1, C102.1, C201.2, C202.2, C301.2, C304.2, C305.2, C306.2, C308.2, C409.2, C423.2, C801.1, C803.1, C804.1, C806.2, C807.1, C808.2, C809.1, C810.1, C811.1, C812.1, D301.2, D802.2, D803.2, D804.2, D1101.3, J1101.A1, J1101.A12, J1101.B1, J1101.B12, J1101.S1, K101.3, NT401.2, NT402.2, P101.1, P102.2, P102.7, P103.4, P104.1, P106.6, P801.1, P901.1, R103.2, R104.2, R203.2, R303.2, R409.2, R411.2, R413.2, R415.2, R804.2, R1103.2, R1104.2, U201.2, U301.1, U401.41, U801.18, U801.63, X801.3
GNDA: C406.2, C802.1, C805.1, NT401.1, U401.27, U801.12
GNDD: C401.2, C402.2, C403.2, C404.2, C405.2, C408.1, C413.2, C414.2, C416.2, C417.2, C418.2, C419.2, C420.2, C421.2, C422.2, C425.2, C502.2, C503.2, C504.2, C505.2, C506.2, C602.2, C603.2, C604.2, C605.2, C606.2, C702.2, C703.2, C704.2, C705.2, C706.2, D401.2, J402.1, J406.2, NT402.1, NT503.2, NT603.2, NT703.2, R404.1, R406.2, R417.2, R506.2, R507.2, R606.2, R607.2, R706.2, R707.2, U401.1, U401.49
NRST: C804.2, P801.2, U801.7
unnamed: C201.1, R201.2, R202.2
unnamed: C303.1, L301.2, U301.2
unnamed: C303.2, U301.6
unnamed: C307.2, R302.2, R303.1, U301.4
unnamed: C407.1, U401.4
unnamed: C407.2, U401.3
unnamed: C412.2, C415.1, R407.1
unnamed: J1101.A4, J1101.A9, J1101.B4, J1101.B9
unnamed: J1101.A5, R1104.1
unnamed: J1101.A6, J1101.B6, R1102.2
unnamed: J1101.A7, J1101.B7, R1101.2
unnamed: J1101.B5, R1103.1
unnamed: K101.1, R102.2
unnamed: K101.2, R101.1
unnamed: Q501.2, R502.1
unnamed: Q502.2, R503.1
unnamed: Q503.2, R504.1
unnamed: Q504.2, R505.1
unnamed: Q601.2, R602.1
unnamed: Q602.2, R603.1
unnamed: Q603.2, R604.1
unnamed: Q604.2, R605.1
unnamed: Q701.2, R702.1
unnamed: Q702.2, R703.1
unnamed: Q703.2, R704.1
unnamed: Q704.2, R705.1
unnamed: R203.1, U201.8
SWCLK: P801.4, U801.49
SWDIO: P801.3, U801.46

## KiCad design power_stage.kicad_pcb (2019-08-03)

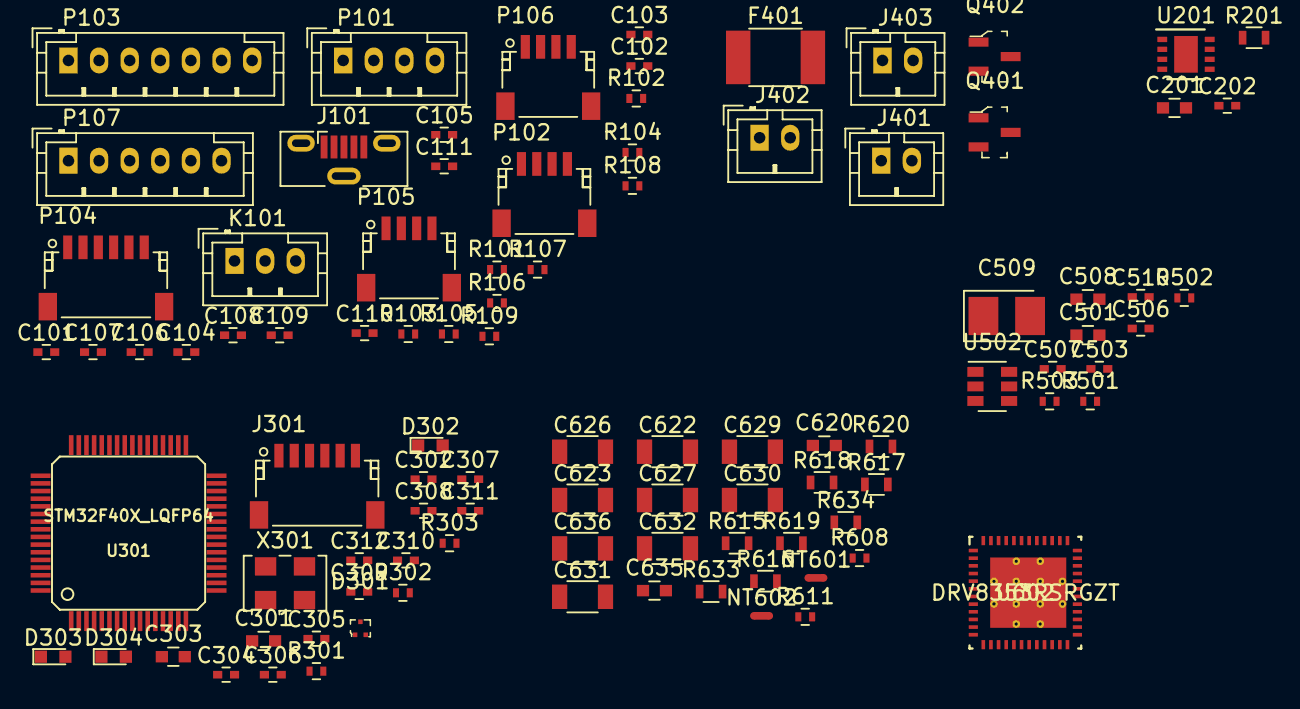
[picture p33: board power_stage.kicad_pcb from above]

Board: 2 copper layers, 96 parts (0 on the bottom side), 69 nets, no tracks yet.

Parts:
C101, C110, C304: 100n; C_0402
C102, C106, C107, C108, C109, C111, C202, C503, C506, C507: 100nf; C_0402
C103, C104, C105: 4.7nf; C_0402
C201, C301, C303: 2.2u; C_0603
C302, C305, C307, C309, C310, C311, C312: 2.2u; C_0402
C306, C308: 15p; C_0402
C501, C508: 2.2uf; C_0603
C509: 100uf; CP_Tantalum_Case-B_EIA-3528-21_Reflow
C510: NP; C_0402
C620, C635: 1uf; C_0603
C622, C623, C626, C627, C629, C630, C631, C632, C636: 100v_1.0uF; C_1206
D301: TPD2EUSB30DRTR; SOT-3
D302: BLUE; LED_0603
D303: GREEN; LED_0603
D304: RED; LED_0603
F401: 0.5A polyfuse; R_1812
J101: USB_B_Micro; USB_Micro-B_Vertical_Molex-105133-0001
J301: SWD; JST_SH_SM06B-SRSS-TB_06x1.00mm_Angled
J401, J402, J403: Conn_01x02; JST_PH_B2B-PH-K_02x2.00mm_Straight
K101: SERVO; JST_PH_B3B-PH-K_03x2.00mm_Straight
NT601, NT602: Net-Tie_2; NetTie-2_SMD_Pad0.5mm
P101: CANBUS; JST_PH_B4B-PH-K_04x2.00mm_Straight
P102: Serial3; JST_SH_SM04B-SRSS-TB_04x1.00mm_Angled
P103: CTRL_SIGNALS; JST_PH_B7B-PH-K_07x2.00mm_Straight
P104: SPI; JST_SH_SM06B-SRSS-TB_06x1.00mm_Angled
P105: Serial1/tim4; JST_SH_SM04B-SRSS-TB_04x1.00mm_Angled
P106: I2C; JST_SH_SM04B-SRSS-TB_04x1.00mm_Angled
P107: HALL/Encoder; JST_PH_B6B-PH-K_06x2.00mm_Straight
Q401, Q402: IRLML6344TRPBF; SOT-23-3
R101: 100R; R_0402
R102, R103: 100k; R_0402
R104, R105: 22R; R_0402
R106, R107, R108, R608, R611: 2k2; R_0402
R109: 10k; R_0402
R201: 220R; R_0603
R301, R302, R303, R501: 1k; R_0402
R502: R33.2k 0.1%; R_0402
R503: 10k 0.1%; R_0402
R615, R616, R617, R618, R619, R620: 10R; R_0603
R633: 39k; R_0603
R634: 2k2; R_0603
U201: TJA1051TK-3; DFN-8-1EP_3x3mm_Pitch0.65mm
U301: STM32F40X_LQFP64; lqfp64_pad_mod
U502: TPS561201; SOT-23-6
U602: DRV8353RSRGZT; DRV8353RHRGZR
X301: 8MHz 10ppm; Oscillator_SMD_EuroQuartz_XO53-4pin_5.0x3.2mm

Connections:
+3V3: C202.1, C302.2, C305.2, C307.2, C309.2, C310.2, C311.2, C312.2, C507.1, C508.1, C509.1, C510.1, J301.1, P102.3, P103.1, P104.1, P105.3, P106.3, P107.1, R106.2, R107.2, R108.2, R109.2, R301.2, R502.1, U201.5, U301.1, U301.13, U301.19, U301.32, U301.48, U301.64, U602.26
+5V: C201.1, U201.3
+12V: C501.1, C503.1, C620.1, F401.1, R501.2, U502.3
+BATT: U602.6, U602.43
/12vbuck_SENSE: C111.1, U301.21
/PHASE_CURRENT_1_ADC: C103.1, U301.8
/PHASE_CURRENT_2_ADC: C104.1, U301.9
/PHASE_CURRENT_3_ADC: C105.1, U301.10
/PHASE_V_1_ADC: C107.1, U301.14
/PHASE_V_2_ADC: C108.1, U301.15
/PHASE_V_3_ADC: C109.1, U301.16
/aux_outputs/AUX1_PWM: Q401.1, U301.22
/aux_outputs/AUX2_PWM: Q402.1, U301.23
/drv_power_stage/EN0: U602.35, U602.37, U602.39
/drv_power_stage/HG: R616.2, R617.2, R619.2
/drv_power_stage/LG: R615.2, R618.2, R620.2
/drv_power_stage/PHASE_R: C635.2, R633.2
/drv_power_stage/PHASE_V_SENSE: R633.1, R634.1
/sheet5B3977DF/CANH: P101.3, R201.1, U201.7
/sheet5B3977DF/CANL: P101.2, R201.2, U201.6
/sheet5B3977DF/CAN_RX: U201.4, U301.61
/sheet5B3977DF/CAN_TX: U201.1, U301.62
/sheet5B3977E0/ADC_BRAKE: P103.4, R103.1, U301.27
/sheet5B3977E0/ADC_TEMP: C102.1, U301.24
/sheet5B3977E0/ADC_THROTTLE: P103.3, R102.1, U301.26
/sheet5B3977E0/ADC_VBUS: C106.1, U301.11
/sheet5B3977E0/HALL_1: P107.3, R106.1, U301.37
/sheet5B3977E0/HALL_2: P107.4, R107.1, U301.38
/sheet5B3977E0/HALL_3: P107.5, R108.1, U301.39
/sheet5B3977E0/LED_GREEN: R302.2, U301.3
/sheet5B3977E0/LED_RED: R303.2, U301.4
/sheet5B3977E0/SCL_2: P106.1, U301.29
/sheet5B3977E0/SDA_2: P106.2, U301.30
/sheet5B3977E0/SERVO: C101.2, R101.1, U301.17
/sheet5B3977E0/SPI3_MISO: P104.3, U301.56
/sheet5B3977E0/SPI3_MOSI: P104.2, U301.53
/sheet5B3977E0/SPI3_NSS: P104.5, U301.50
/sheet5B3977E0/SPI3_SCK: P104.4, U301.55
/sheet5B3977E0/TEMP_MOTOR: C110.2, P107.2, R109.1, U301.25
/sheet5B3977E0/USART1_RX: P105.1, U301.59
/sheet5B3977E0/USART1_TX: P105.2, U301.58
/sheet5B3977E0/USART3_RX: P102.1, U301.52
/sheet5B3977E0/USART3_TX: P102.2, U301.51
/sheet5B3977E0/USB_DM: D301.2, R105.1, U301.44
/sheet5B3977E0/USB_DP: D301.1, R104.1, U301.45
/sheet5B3977E0/VCAP1: C303.2, U301.31
/sheet5B3977E0/VCAP2: C301.2, U301.47
GND: C101.1, C102.2, C103.2, C104.2, C105.2, C106.2, C107.2, C108.2, C109.2, C110.1, C111.2, C201.2, C202.2, C301.1, C302.1, C303.1, C304.1, C305.1, C306.2, C307.1, C308.2, C309.1, C310.1, C311.1, C312.1, C501.2, C503.2, C507.2, C508.2, C509.2, D301.3, D302.2, D303.2, D304.2, J101.5, J101.6, J301.3, K101.3, NT601.2, NT602.1, P101.1, P102.4, P103.2, P103.7, P104.6, P105.4, P106.4, P107.6, R102.2, R103.2, R503.2, R608.2, R611.2, R634.2, U201.2, U201.8, U201.9, U301.12, U301.18, U301.60, U301.63, U502.1, X301.3
GNDD: NT601.1, U602.1, U602.27, U602.41, U602.49
GNDPWR: C620.2, C622.2, C623.2, C626.2, C627.2, C629.2, C630.2, C631.2, C632.2, C636.2, J403.2, NT602.2, Q401.2, Q402.2
NRST: C304.2, J301.5, U301.7
unnamed: C306.1, U301.5, X301.1
unnamed: C308.1, U301.6, X301.2
unnamed: C506.1, U502.2
unnamed: C506.2, U502.6
unnamed: C510.2, R502.2, R503.1, U502.4
unnamed: D302.1, R301.1
unnamed: D303.1, R302.1
unnamed: D304.1, R303.1
unnamed: F401.2, J401.1, J402.1, J403.1
unnamed: J101.2, R105.2
unnamed: J101.3, R104.2
unnamed: J401.2, Q401.3
unnamed: J402.2, Q402.3
unnamed: K101.1, R101.2
unnamed: R501.1, U502.5
SWCLK: J301.2, U301.49
SWDIO: J301.4, U301.46
VBUS: C622.1, C623.1, C626.1, C627.1, C629.1, C630.1, C631.1, C632.1, C636.1

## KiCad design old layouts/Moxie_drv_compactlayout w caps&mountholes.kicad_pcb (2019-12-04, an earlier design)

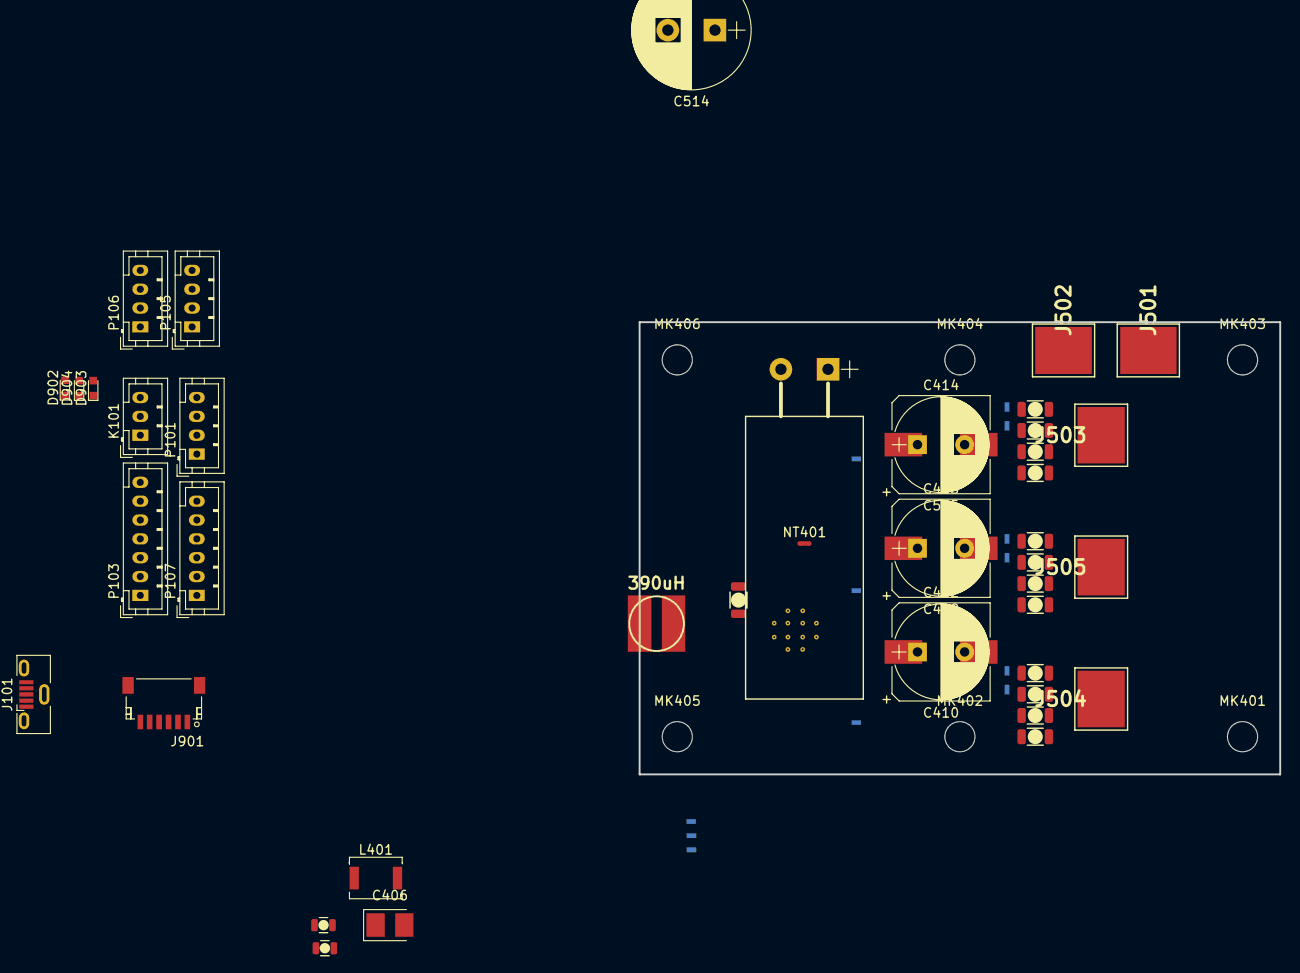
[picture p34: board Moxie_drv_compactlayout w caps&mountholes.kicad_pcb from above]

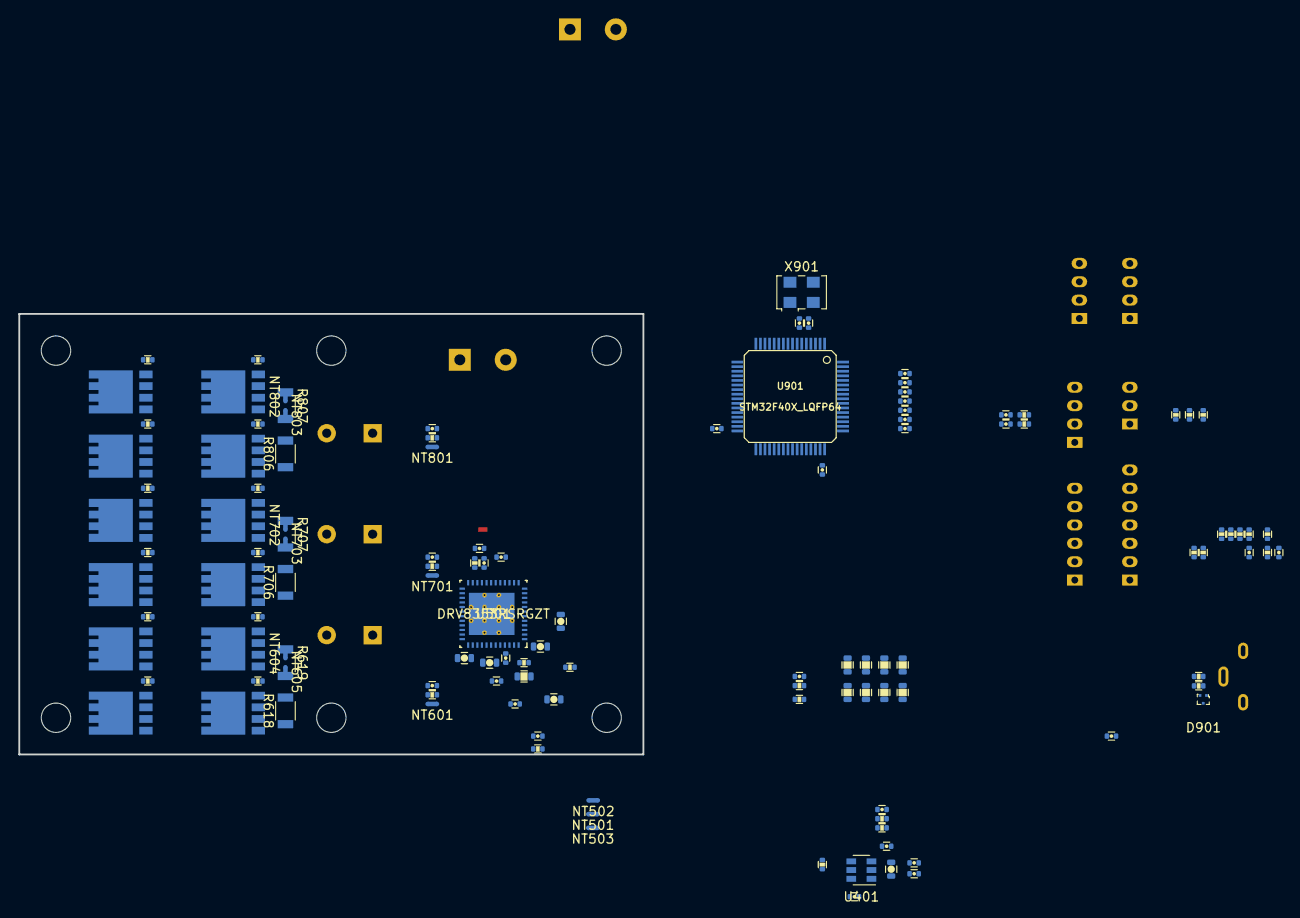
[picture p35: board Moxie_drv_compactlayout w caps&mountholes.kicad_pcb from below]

Board: 4 copper layers, 68.0 x 48.0 mm, 170 parts (121 on the bottom side), 110 nets, no tracks yet.

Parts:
C101, C107, C904: 100n; C_0402
C201: 4.7nf; C_0402
C202, C901, C902, C903, C905, C907, C909, C910, C911, C912: 2.2u; C_0402
C401: 2.2uf; C_0603
C402, C403, C404, C408: 100nf; C_0402
C405: 2.2uf; C_0402
C406: 100uf; CP_Tantalum_Case-B_EIA-3528-21_Reflow
C407: NP; C_0402
C409, C410, C515: 20uF; CP_Elec_10x10.5
C411: 560uF; CP_Radial_D12.5mm_P5.00mm_horiz
C412, C413, C414: 56uF; CP_Radial_D10.0mm_P5.00mm
C501: 10uF; C_0805
C502: 1.5uF; C_1206
C503, C504: 0.1uF; C_0603
C505: 0.47uF; C_0402
C506: 0.1uF; C_0402
C507: 0.047uF; C_0402
C508, C509, C511: 1uF; C_0603
C510: 0.01uF; C_0402
C512: 18nF; C_0402
C513: 22uF; C_0805
C514: 560uF; CP_Radial_D12.5mm_P5.00mm
C601, C701, C801: 2.2nF; C_0402
C602, C603, C604, C606, C702, C703, C704, C706, C802, C803, C804, C806: 1uF; C_1206
C906, C908: 15p; C_0402
D901: TPD2EUSB30DRTR; SOT-3
D902: BLUE; LED_0603
D903: GREEN; LED_0603
D904: RED; LED_0603
J101: USB_B_Micro; USB_Micro-B_Vertical_Molex-105133-0001
J501: +Vbat; 1PAD_6x5mm
J502: Gnd; 1PAD_6x5mm
J503: A; 1PAD_6x5mm
J504: B; 1PAD_6x5mm
J505: C; 1PAD_6x5mm
J901: SWD; JST_SH_SM06B-SRSS-TB_06x1.00mm_Angled
K101: SERVO; JST_PH_B3B-PH-K_03x2.00mm_Straight
L401: 3.3uH; L_Neosid_Ms42
L501: 390uH; inductor_smd_5.8mmx4.8hmm
MK401, MK402, MK403, MK404, MK405, MK406: Mounting_Hole; MountingHole_3.2mm_M3_DIN965
NT401, NT501, NT502, NT503, NT601, NT604, NT605, NT701, NT702, NT703, NT801, NT802, NT803: Net-Tie_2; NetTie-2_SMD_Pad0.5mm
P101: CANBUS; JST_PH_B4B-PH-K_04x2.00mm_Straight
P103: CTRL_SIGNALS; JST_PH_B7B-PH-K_07x2.00mm_Straight
P105: Serial1/tim4; JST_PH_B4B-PH-K_04x2.00mm_Straight
P106: I2C; JST_PH_B4B-PH-K_04x2.00mm_Straight
P107: HALL/Encoder; JST_PH_B6B-PH-K_06x2.00mm_Straight
Q601, Q602, Q603, Q604, Q701, Q702, Q703, Q704, Q801, Q802, Q803, Q804: TPH2R608NH,L1Q; SOP8_Advance
R101: 0Ω; R_0402
R102, R603, R703, R803: 100Ω; R_0402
R103, R104: 100kΩ; R_0402
R105, R106: 22R; R_0402
R107, R108, R109: 2k2Ω; R_0402
R110, R516: 10kΩ; R_0402
R201, R202: 120R; R_0402
R401, R901, R902, R903: 1k; R_0402
R402: R33.2k 0.1%; R_0402
R403: 10k 0.1%; R_0402
R501: 1kOhm; C_0402
R502: 10kΩ; C_0402
R503: 560kΩ; R_0402
R504: 200kΩ; R_0402
R505: 5.1kΩ; R_0402
R506: 1.0kΩ; R_0402
R507: 910mΩ; R_0603
R508, R510, R512, R514: 47kΩ; R_0603
R509, R511, R513, R515: 2.2kΩ; R_0603
R517: NTC 10kΩ; R_0402
R601, R602, R604, R605, R701, R702, R704, R705, R801, R802, R804, R805: 5Ω; R_0402
R618, R619, R706, R707, R806, R807: 1mΩ; R_1206
U401: TPS561201; SOT-23-6
U501: DRV8353RSRGZT; DRV8353RHRGZR
U901: STM32F40X_LQFP64; lqfp64_pad_mod
X901: 8MHz 10ppm; Oscillator_SMD_EuroQuartz_XO53-4pin_5.0x3.2mm

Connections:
+3V3: C202.1, C404.1, C405.1, C406.1, C407.1, C902.2, C905.2, C907.2, C909.2, C910.2, C911.2, C912.2, J901.1, L401.1, NT503.2, P103.1, P105.3, P106.3, P107.1, R101.2, R107.2, R108.2, R109.2, R110.2, R402.1, R501.1, R502.1, R516.1, R901.2, U901.1, U901.13, U901.19, U901.32, U901.48, U901.64
+12V: C401.1, C402.1, C501.1, C503.1, C513.1, R401.2, R507.2, U401.3, U501.5
+BATT: C409.1, C410.1, C411.1, C412.1, C413.1, C414.1, C502.1, C504.1, C514.1, C515.1, C602.1, C603.1, C604.1, C606.1, C702.1, C703.1, C704.1, C706.1, C802.1, C803.1, C804.1, C806.1, J501.1, NT401.1, Q601.1, Q603.1, Q701.1, Q703.1, Q801.1, Q803.1, R503.1, R514.1, U501.43
/CAN_tranciever/CANH: P101.3, R201.1
/CAN_tranciever/CANL: P101.2, R202.1
/Microcontroller/ADC_BRAKE: P103.4, R104.1, U901.27
/Microcontroller/ADC_TEMP: C408.1, R516.2, R517.1, U901.24
/Microcontroller/ADC_THROTTLE: P103.3, R103.1, U901.26
/Microcontroller/ADC_VBUS: R514.2, R515.1, U901.11
/Microcontroller/BRAKE_SW: P103.6, U901.57
/Microcontroller/FAULT: R502.2, U501.28, U901.33
/Microcontroller/H1: U501.34, U901.41
/Microcontroller/H2: U501.36, U901.42
/Microcontroller/H3: U501.38, U901.43
/Microcontroller/HALL_1: P107.3, R107.1, U901.37
/Microcontroller/HALL_2: P107.4, R108.1, U901.38
/Microcontroller/HALL_3: P107.5, R109.1, U901.39
/Microcontroller/L1: U501.35, U901.34
/Microcontroller/L2: U501.37, U901.35
/Microcontroller/L3: U501.39, U901.36
/Microcontroller/LED_GREEN: R902.2, U901.3
/Microcontroller/LED_RED: R903.2, U901.4
/Microcontroller/SCL_2: P106.1, U901.29
/Microcontroller/SDA_2: P106.2, U901.30
/Microcontroller/SERVO: C101.2, R102.1, U901.17
/Microcontroller/TEMP_MOTOR: C107.2, P107.2, R110.1, U901.25
/Microcontroller/USART1_RX: P105.1, U901.59
/Microcontroller/USART1_TX: P105.2, U901.58
/Microcontroller/USB_DM: D901.2, R106.1, U901.44
/Microcontroller/USB_DP: D901.1, R105.1, U901.45
/Microcontroller/VCAP1: C903.2, U901.31
/Microcontroller/VCAP2: C901.2, U901.47
/drv_power_stage/3.3_IREF: C506.1, NT503.1, U501.26
/drv_power_stage/A_ISENSE: U501.25, U901.8
/drv_power_stage/A_VSENSE: R508.2, R509.1, U901.14
/drv_power_stage/B_ISENSE: U501.24, U901.9
/drv_power_stage/B_VSENSE: R510.2, R511.1, U901.15
/drv_power_stage/C_ISENSE: U501.23, U901.10
/drv_power_stage/C_VSENSE: R512.2, R513.1, U901.16
/drv_power_stage/DRV_SDO: R501.2, U501.29
/drv_power_stage/ENABLE: U501.33, U901.40
/drv_power_stage/GDRV_VSENSE: C512.1, R505.2, R506.1, U501.48
/drv_power_stage/PHASE_A: J503.1, NT801.2, Q801.3, Q802.1, Q803.3, Q804.1, R508.1
/drv_power_stage/PHASE_B: J504.1, NT601.2, Q601.3, Q602.1, Q603.3, Q604.1, R510.1
/drv_power_stage/PHASE_C: J505.1, NT701.2, Q701.3, Q702.1, Q703.3, Q704.1, R512.1
/drv_power_stage/buck_rcl: R504.2, U501.46
/drv_power_stage/power_phase_A/H_GATE: R801.2, R804.2, U501.8
/drv_power_stage/power_phase_A/H_SWITCH: NT801.1, U501.9
/drv_power_stage/power_phase_A/L_GATE: R802.2, R805.2, U501.10
/drv_power_stage/power_phase_A/NR_SENSE: C801.1, R803.1, U501.12
/drv_power_stage/power_phase_A/PH_GND_LOW: NT802.2, Q802.3, Q804.3, R806.1, R807.1
/drv_power_stage/power_phase_A/PR_SENSE: C801.2, NT802.1, U501.11
/drv_power_stage/power_phase_B/H_GATE: R601.2, R604.2, U501.17
/drv_power_stage/power_phase_B/H_SWITCH: NT601.1, U501.16
/drv_power_stage/power_phase_B/L_GATE: R602.2, R605.2, U501.15
/drv_power_stage/power_phase_B/NR_SENSE: C601.1, R603.1, U501.13
/drv_power_stage/power_phase_B/PH_GND_LOW: NT604.2, Q602.3, Q604.3, R618.1, R619.1
/drv_power_stage/power_phase_B/PR_SENSE: C601.2, NT604.1, U501.14
/drv_power_stage/power_phase_C/H_GATE: R701.2, R704.2, U501.18
/drv_power_stage/power_phase_C/H_SWITCH: NT701.1, U501.19
/drv_power_stage/power_phase_C/L_GATE: R702.2, R705.2, U501.20
/drv_power_stage/power_phase_C/NR_SENSE: C701.1, R703.1, U501.22
/drv_power_stage/power_phase_C/PH_GND_LOW: NT702.2, Q702.3, Q704.3, R706.1, R707.1
/drv_power_stage/power_phase_C/PR_SENSE: C701.2, NT702.1, U501.21
GND: C101.1, C107.1, C201.2, C202.2, C401.2, C402.2, C404.2, C405.2, C406.2, C409.2, C410.2, C411.2, C412.2, C413.2, C414.2, C514.2, C515.2, C901.1, C903.1, C904.1, C906.2, C907.1, C908.2, C909.1, C910.1, C911.1, C912.1, D901.3, D902.2, D903.2, D904.2, J101.5, J101.6, J502.1, J901.3, K101.3, NT501.2, NT502.2, P101.1, P103.2, P103.7, P105.4, P106.4, P107.6, R103.2, R104.2, R403.2, U401.1, U501.41, U901.18, U901.60, U901.63, X901.3
GNDA: C408.2, C506.2, C902.1, C905.1, NT501.1, U501.27, U901.12
GNDD: C501.2, C502.2, C503.2, C504.2, C505.2, C508.1, C509.2, C513.2, C602.2, C603.2, C604.2, C606.2, C702.2, C703.2, C704.2, C706.2, C802.2, C803.2, C804.2, C806.2, NT502.1, NT605.2, NT703.2, NT803.2, R504.1, R506.2, R509.2, R511.2, R513.2, R515.2, R517.2, R618.2, R619.2, R706.2, R707.2, R806.2, R807.2, U501.1, U501.49
NRST: C904.2, J901.5, U901.7
unnamed: C201.1, R201.2, R202.2
unnamed: C403.1, L401.2, U401.2
unnamed: C403.2, U401.6
unnamed: C407.2, R402.2, R403.1, U401.4
unnamed: C505.1, U501.44
unnamed: C507.1, U501.4
unnamed: C507.2, U501.3
unnamed: C508.2, U501.2
unnamed: C509.1, U501.40
unnamed: C510.1, U501.45
unnamed: C510.2, L501.2, U501.42
unnamed: C511.1, NT401.2, U501.6
unnamed: C511.2, U501.7
unnamed: C512.2, L501.1, R505.1, R507.1
unnamed: C906.1, U901.5, X901.1
unnamed: C908.1, U901.6, X901.2
unnamed: D902.1, R901.1
unnamed: D903.1, R902.1
unnamed: D904.1, R903.1
unnamed: J101.2, R106.2
unnamed: J101.3, R105.2
unnamed: K101.1, R102.2
unnamed: K101.2, R101.1
unnamed: NT605.1, R603.2
unnamed: NT703.1, R703.2
unnamed: NT803.1, R803.2
unnamed: Q601.2, R601.1
unnamed: Q602.2, R602.1
unnamed: Q603.2, R604.1
unnamed: Q604.2, R605.1
unnamed: Q701.2, R701.1
unnamed: Q702.2, R702.1
unnamed: Q703.2, R704.1
unnamed: Q704.2, R705.1
unnamed: Q801.2, R801.1
unnamed: Q802.2, R802.1
unnamed: Q803.2, R804.1
unnamed: Q804.2, R805.1
unnamed: R401.1, U401.5
unnamed: R503.2, U501.47
SWCLK: J901.2, U901.49
SWDIO: J901.4, U901.46

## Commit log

2019-08-03 initial WIP for the moxie drive mini with drv
    [CAN.sch, MoxiE_Control_board.kicad_pcb, MoxiE_Control_board.sch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]
2019-08-03 updated readme and used updated 3.3v can controller since there is no 5v rail
    [CAN.sch]
2019-12-04 further progress finalising schematic and power stage laied out. drv is fanned out, and logic is starting to be routed
    [60x60 cap edge.kicad_pcb, 65x56 coming together.kicad_pcb, CAN.sch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]
2020-01-12 connector layout basically finalised. drv gate layout finished mcu layout starting
    [60x60 cap edge.kicad_pcb, 65x56 coming together.kicad_pcb, BM04B-SRSS-TB.STEP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]
2020-01-31 pre pin refactor/remap incremental commit
    [33to5.sch, 5v aux.sch, CAN.sch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]

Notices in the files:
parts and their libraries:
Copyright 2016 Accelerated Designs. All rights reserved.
